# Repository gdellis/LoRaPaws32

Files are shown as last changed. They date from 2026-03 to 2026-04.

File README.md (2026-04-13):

# LoRaPaws32

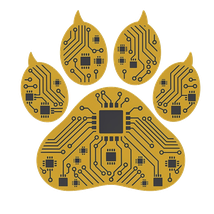
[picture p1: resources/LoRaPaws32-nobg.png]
LoRaPaws32 Logo








LoRa-based pet tracker using LoRa radio to communicate with a home base station, which forwards data to the cloud.

## Features

- **GPS tracking** with NEO-6M module and ~2.5m accuracy
- **LoRa radio** (SX1262) for long-range communication to base station
- **BLE fallback** for direct phone connectivity when in range
- **Motion detection** via LIS3DH accelerometer for intelligent wake cycles
- **Deep sleep** for maximum battery life
- **Web UI** on base station for live tracking and configuration

## Hardware

| Component | Part |
|---|---|
| MCU | ESP32-C6 (RISC-V) |
| LoRa | Seeed Wio-SX1262 for XIAO (915 MHz) |
| GPS | u-blox NEO-6M |
| Accelerometer | LIS3DH |
| Battery | LiPo 500mAh |

See [docs/hardware/DESIGN.md](docs/hardware/DESIGN.md) for full hardware documentation.

## Architecture

```mermaid
flowchart LR
    T[Tracker<br/>ESP32C6] <-->|BLE| P[Phone]
    T -->|LoRa| B[Base Station<br/>Raspberry Pi]
    B -->|MQTT| H[(HiveMQ<br/>Broker)]
    B -->|HTTP| W[Web UI<br/>Flask]
```

## Project Structure

```
LoRaPaws32/
├── firmware/              # C++ ESP-IDF firmware
│   ├── CMakeLists.txt
│   ├── build.sh          # Docker-based build
│   ├── sdkconfig.defaults
│   └── main/
│       └── main.cpp       # Application entry
├── hardware/              # KiCad PCB designs & enclosure
│   ├── tracker/          # Pet tracker PCB
│   ├── base_station/     # Base station PCB
│   └── enclosure/        # 3D printed case
├── base_station/         # Python Flask web app
├── docs/                 # Documentation
│   ├── hardware/         # Hardware design docs
│   ├── firmware/         # Firmware docs
│   ├── datasheets/       # Component datasheets
│   └── plans/            # Implementation plans
├── third_party/          # Vendor libraries
└── .github/workflows/     # CI/CD pipelines
```

## Firmware

Built with C++ and ESP-IDF framework using Docker.

### Prerequisites

- Docker

### Build

```bash
cd firmware
./build.sh
```

### IDE Setup

**Note:** The ESP-IDF framework uses the Xtensa toolchain (Xtensa-specific compiler
flags like `-mlongcalls`, `-fno-shrink-wrap`, `-fstrict-volatile-bitfields`).
When using clangd or other GCC-based LSP servers, you may see warnings such as:

```
Unknown argument '-mlongcalls'; did you mean '-mlong-calls'?
Unknown argument: '-fno-shrink-wrap'
Unknown argument: '-fstrict-volatile-bitfields'
```

These warnings are expected and do not affect the build. They occur because:
- ESP-IDF compiles with `xtensa-esp-elf-gcc` which accepts Xtensa-specific flags
- Host-based tests use standard GCC
- clangd uses host GCC which doesn't recognize these flags

The warnings are cosmetic and can be safely ignored. Actual compilation uses the correct
toolchain via `idf.py build` or `./build.sh`.

### Flash

```bash
docker run --rm -v $(pwd):/workspace -w /workspace espressif/idf:v5.3.1 \
  sh -c ". /opt/esp/idf/export.sh && idf.py -p /dev/ttyACM0 flash monitor"
```

## Base Station

Python 3 on Raspberry Pi with:
- Flask web server
- SQLite database
- Leaflet.js + OpenStreetMap for live tracking

## Documentation

| Document | Description |
|---|---|
| [docs/hardware/DESIGN.md](docs/hardware/DESIGN.md) | Full hardware design |
| [docs/hardware/BOM.md](docs/hardware/BOM.md) | Bill of materials |
| [docs/plans/](docs/plans/) | Implementation plans |
| [docs/firmware/DEPENDENCIES.md](docs/firmware/DEPENDENCIES.md) | Build dependencies |

## License

- **Firmware** (`firmware/`): [Personal Use Only](LICENSE)
- **Hardware & Documentation** (`hardware/`, `docs/`): [CC BY-NC-SA 4.0](LICENSE-DESIGNS)

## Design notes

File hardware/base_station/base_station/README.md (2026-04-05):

# Base Station KiCad Project

KiCad 8 project for the pet tracker base station carrier board.

## Project Files

```
base_station/
├── base_station.kicad_pro   # Project file (open this in KiCad)
├── base_station.kicad_sch   # Schematic
├── base_station.kicad_pcb   # PCB layout
└── sym/                     # Custom symbol library
    └── base_station.kicad_sym
```

## Components

| Ref | Component | Footprint |
|-----|---|---|
| U1 | XIAO ESP32S3 | SeeedStudio:XIAO-ESP32S3 |
| U2 | NEO-6M GPS | GPS:GPS-NEO-6M |
| U3 | MCP1700 LDO | Package_TO_SOT_SMD:SOT-23-3 |
| J1 | USB-C | Connector_USB:USB_C_Receptacle |
| J2 | Battery | Connector_JST:JST_PH_B2B-PH-K |
| D1 | Status LED | Device:LED_0603 |
| R1 | LED Resistor (470R) | Resistor_SMD:R_0603_1608Metric |
| C1 | Decoupling Cap (10µF) | Capacitor_SMD:C_0603_1608Metric |

## Pin Connections

| Signal | XIAO Pin | Connection |
|---|---|---|
| GPS_TX | D7 (GPIO6) | GPS RX |
| GPS_RX | D6 (GPIO7) | GPS TX |
| GPS_PPS | D0 (GPIO0) | GPS PPS (optional) |
| LED_STATUS | D10 (GPIO10) | R1 → LED |

## Setup

1. Initialize the OPL submodule:

   ```bash
   git submodule update --init --recursive
   ```

2. Open `base_station.kicad_pro` in KiCad 8+

3. Configure library paths:
   - **Symbol Libraries**: Add
     `../../third_party/OPL_Kicad_Library/Seeed Studio XIAO ESP32S3/lib/` and
     `../../third_party/OPL_Kicad_Library/Seeed Studio Wio SX1262 for XIAO ESP32S3/lib/`
   - **Footprint Libraries**: Same paths with `.pretty` suffix

4. Add components from libraries to schematic

5. Run ERC (Electrical Rules Check) and DRC (Design Rules Check)

## Notes

- This is a starting point — verify all connections against component datasheets
- The Wio-SX1262 stacks on XIAO via board-to-board connector (no wiring needed)
- GPS module is powered from XIAO's 3.3V rail
- Battery (3.7V LiPo) → MCP1700 → 3.3V for XIAO
- Board outline: 100mm x 80mm (adjust as needed)

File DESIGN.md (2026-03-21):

# Pet Tracker ESP32 Design

## Overview

An ESP32-based pet tracker using LoRa radio to communicate with a home base station,
which forwards data to the cloud. The device sleeps deeply between updates to maximize
battery life, waking only to acquire GPS and transmit.

**Target use case**: Pets that roam outdoors, tracked via a home base station with
cloud connectivity for remote monitoring via mobile app.

---

## Hardware

### Main Board: Seeed Studio XIAO ESP32C3

- **MCU**: ESP32-C3 (RISC-V, 160 MHz, WiFi/Bluetooth 5.0 LE)
- **Flash**: 4 MB
- **USB**: USB-C for charging and programming
- **Size**: 21 x 17.5 mm — very compact
- **Note**: ESP32-C3 has no floating-point unit (no FPU). Keep math simple or use soft-float.

### Alternative Board: XIAO ESP32S3

- **MCU**: ESP32-S3 (Xtensa, 240 MHz, with FPU)
- **Bluetooth 5.0 LE + BLE
- **USB**: USB-C
- **Size**: 21 x 17.5 mm
- **Preferred if**: You want BLE fallback for direct phone connectivity and better floating-point performance

**Recommendation**: Use **ESP32-S3** for headroom (FPU, more RAM, BLE support).

### GPS Module: u-blox NEO-6M (or compatible)

- **Interface**: UART (TX/RX)
- **Accuracy**: ~2.5 m CEP
- **Operating voltage**: 2.7–3.6 V
- **Cold start**: ~27 s typical
- **Hot start**: ~1 s
- **Active current**: ~20–25 mA during acquisition
- **Sleep current**: ~1 mA (if supported)

**Pin Mapping (XIAO → GPS)**:

| XIAO Pin | GPS Module | Function |
|---|---|---|
| D4 (GPIO20) | TX | GPS data out → XIAO RX |
| D5 (GPIO21) | RX | XIAO data out → GPS TX |
| 3V3 | VCC | Power (or via LDO if needed) |
| GND | GND | Ground |

**Alternative GPS modules**:

- **MAX-M10S**: Lower power (~15 mA), faster fix, U-blox M10 platform
- **Quectel L76B**: Integrated, cheaper, but higher power
- **ATGM336H**: Very cheap, adequate for pet tracker use case

**Note**: NEO-6M is 3.3V compatible but draws significant current. Consider using a GPIO-controlled power switch to completely cut power between GPS fixes.

### Power Management

- **LDO**: Low-dropout regulator (e.g., MCP1700, 3.3 V output) for stable power
- **Voltage divider**: For battery voltage monitoring via ADC (measure Vbat)
- **Power switch**: GPIO-controlled MOSFET to cut GPS power when not in use
- **Sleep current target**:
  - SX1262: ~1 µA (very low, LoRa radio itself)
  - ESP32-S3 deep sleep: ~10–20 µA (CPU off, RTC memory retained)
  - GPS: Must be powered off completely (no true sleep on NEO-6M)
  - **Total target in deep sleep**: < 50 µA

**Power architecture**:

```
LiPo (3.7V) → MCP1700 (3.3V) → XIAO + Wio-SX1262
                    ↓
            GPIO-controlled switch → GPS module
                    ↓
            ADC voltage divider → Battery monitoring
```

### Other Components

- **Indicator LED**: Single RGB or single-color LED for status (low current, ~5 mA)
- **Reset button**: Tactile button for manual reset
- **Antenna connectors**: U.FL for LoRa (Wio-SX1262 has built-in U.FL)
- **Accelerometer**: LIS3DH (I2C) for motion detection — wakes device when pet moves
- **3D printed enclosure**: Custom case for XIAO + Wio-SX1262 + GPS + LIS3DH + battery
  - Consider: PETG or ABS for durability
  - Needs antenna clearance (LoRa U.FL antenna on top of stack)
  - Waterproofing: **silicone gasket** (reusable, adjustable, good seal)

---

## Software Architecture

### Firmware Overview

The tracker firmware is event-driven, built on ESP-IDF's FreeRTOS. Most time is spent in deep sleep; on wake, the system acquires GPS, transmits via LoRa, then returns to sleep.

```mermaid
stateDiagram-v2
    [*] --> BOOT
    BOOT --> IDLE

    state IDLE {
        [*] --> WAITING
        WAITING --> WAITING : no wake source
    }

    IDLE --> ACQUIRING_GPS : wake (timer/button/motion)
    IDLE --> STANDBY : immediate sleep

    state ACQUIRING_GPS {
        [*] --> GPS_POWER_ON
        GPS_POWER_ON --> GPS_WAIT_FIX
        GPS_WAIT_FIX --> GPS_WAIT_FIX : no fix yet
        GPS_WAIT_FIX --> GPS_FIX_OK : valid fix
        GPS_WAIT_FIX --> GPS_TIMEOUT : 60s elapsed
        GPS_TIMEOUT --> GPS_POWER_OFF
        GPS_FIX_OK --> GPS_POWER_OFF
        GPS_POWER_OFF --> [*]
    }

    ACQUIRING_GPS --> TRANSMITTING : fix acquired or timeout
    TRANSMITTING --> STANDBY : TX complete

    state STANDBY {
        [*] --> DEEP_SLEEP
        DEEP_SLEEP --> [*] : wake source fires
    }

    STANDBY --> IDLE : wake source
```

### Module Structure

```
src/
├── main.rs           # Boot, initialization, main task
├── lib.rs            # Library root, shared types, error types
├── gps.rs            # GPS parsing (NMEA), location data types
├── lora/
│   ├── mod.rs        # LoRa trait/interface + shared types
│   └── sx1262.rs     # SX1262 driver implementation
├── power.rs          # Sleep, wake sources, battery monitoring
├── accelerometer.rs  # LIS3DH I2C driver for motion detection
├── ble.rs            # BLE GATT server for direct phone connectivity
├── geofence.rs       # Geofence checking (circle/polygon)
├── config.rs         # NVS storage for device config
└── error.rs          # Error types
```

### Key Interfaces

**GPS Module** (`gps.rs`):

```rust
pub struct GpsData {
    pub latitude:  i32,  // degrees * 1e6
    pub longitude: i32,  // degrees * 1e6
    pub altitude:  u16,  // meters
    pub valid:    bool,
    pub timestamp: u32, // Unix epoch
}

pub trait GpsDriver {
    fn power_on(&mut self) -> Result<()>;
    fn power_off(&mut self) -> Result<()>;
    fn read_fix(&mut self, timeout_ms: u32) -> Result<GpsData>;
}
```

**LoRa Driver** (`lora/mod.rs`):

```rust
pub struct RadioPacket {
    pub device_id:  u32,
    pub latitude:   i32,
    pub longitude:  i32,
    pub altitude:   u16,
    pub battery_mv: u16,
    pub flags:      u8,
    pub timestamp:  u32,
}

pub trait LoRaDriver {
    fn init(&mut self) -> Result<()>;
    fn send(&mut self, packet: &RadioPacket) -> Result<()>;
    fn sleep(&mut self) -> Result<()>;
}
```

**Power Management** (`power.rs`):

```rust
pub enum WakeSource {
    Timer(u32),        // RTC timer, duration in ms
    GpsTimeout,
    Button,
}

pub fn enter_deep_sleep(wake_source: WakeSource) -> !;
pub fn get_battery_voltage() -> u16;  // mV
```

### State Machine Detail

**State: STANDBY (Deep Sleep)**

- CPU off, RTC running
- Wake on: RTC timer, button press
- On wake: transition to IDLE then to appropriate state

**State: ACQUIRING_GPS**

- Turn on GPS via power switch (GPIO MOSFET)
- Poll UART for NMEA sentences (GGA, RMC)
- Parse for valid fix (latitude/longitude present)
- Timeout after 60 s → transmit with `valid=false`
- On valid fix: transition to TRANSMITTING

**State: TRANSMITTING**

- Build 20-byte packet
- Wake SX1262 from sleep
- Configure (SF7, BW125, CR4/5, +17 dBm)
- Send packet
- Wait for ACK or timeout (max 3 retries)
- Transition to STANDBY (deep sleep)

### Timing Configuration

```rust
// Configurable constants
const GPS_TIMEOUT_MS: u32 = 60_000;        // 60 seconds max GPS acquisition
const TX_RETRIES: u8 = 3;
const TX_TIMEOUT_MS: u32 = 5_000;         // Per retry timeout

// Default wake intervals (stored in NVS, configurable)
const DEFAULT_SLEEP_INTERVAL_MS: u32 = 60_000;  // 1 minute when moving
const STATIONARY_SLEEP_INTERVAL_MS: u32 = 300_000;  // 5 minutes when stationary
```

### Startup Sequence

1. **Boot** (ROM bootloader → ESP-IDF bootloader)
2. **Early init**: Configure cache, CPU frequency, Flash
3. **ESP-IDF components init**: System, WiFi (disabled), Bluetooth (disabled)
4. **Rust runtime init**: Global allocator, panic handler
5. **Driver init**:
   - Configure GPIO (power switch, LED, button)
   - Initialize SX1262 (but keep in sleep)
   - Initialize GPS (keep powered off)
6. **Read config** from NVS (device_id, sleep intervals, geofences)
7. **Check wake source**: Timer vs button vs reset
8. **Enter main loop** or **deep sleep**

### Error Handling

```rust
#[derive(Debug, Clone, Copy)]
pub enum TrackerError {
    GpsNoFix,
    GpsTimeout,
    LoraTxFailed,
    LoraNoAck,
    NvsError,
    InvalidConfig,
}

impl TrackerError {
    pub fn is_recoverable(&self) -> bool {
        matches!(self, GpsNoFix | GpsTimeout | LoraTxFailed | LoraNoAck)
    }
}
```

- **Recoverable errors**: Log, continue (e.g., no GPS fix → transmit with valid=false)
- **Unrecoverable errors**: Panic and reboot (e.g., NVS corruption)
- All errors logged via `log::error!` for diagnostics

### Configuration Storage (NVS)

Stored in flash via ESP-IDF's NVS:

| Key | Type | Default | Description |
|-----|---|---|---|
| device_id | u32 | random | Unique device identifier |
| sleep_interval_ms | u32 | 60000 | Normal wake interval |
| stationary_interval_ms | u32 | 300000 | Interval when stationary |
| tx_power | u8 | 17 | LoRa TX power in dBm |
| sf | u8 | 7 | Spreading factor |
| geofence_count | u8 | 0 | Number of configured zones |
| motion_threshold | u16 | 100 | LIS3DH motion threshold (mg) |
| stationary_timeout_ms | u32 | 300000 | Time without motion to be "stationary" |

### Interrupt Handlers

Minimal interrupt handlers in embedded context:

- **GPIO button**: Wake from deep sleep on button press
- **Timer**: Wake from deep sleep on RTC alarm
- **LIS3DH INT1**: Motion detected interrupt (wake on movement)
- **SX1262 DIO1**: Packet TX/RX done interrupt (optional, polling also works)

All heavy processing deferred to main task.

### Base Station (Python on Raspberry Pi)

Raspberry Pi with LoRa hat (e.g., Raspberry Pi LoRa HAT):

```mermaid
flowchart LR
    A[LoRa RX] --> B[Python Parser]
    B --> C[WiFi MQTT Publish]
    C --> D[HiveMQ Broker]
    C --> E[(Optional ACK<br/>to tracker)]
```

- LoRa receiver always listening
- Python script parses packet, publishes to HiveMQ via WiFi
- Optional ACK sent back to tracker after successful publish
- **Web UI** for configuration and live data viewing (Flask + HTML/JS)

### Base Station Web UI

A lightweight Flask web server runs on the Raspberry Pi, providing:

**Features**:
- **Dashboard**: Live view of all tracked pets (location, battery, signal strength)
- **Map view**: OpenStreetMap integration showing pet locations in real-time
- **Configuration**: WiFi SSID/password, MQTT broker address, LoRa settings
- **Geofence management**: Add/edit/delete geofence zones
- **Device management**: Register new trackers, view device status
- **Alerts**: Geofence breach notifications (browser notifications)

**Tech stack**:
- **Backend**: Python Flask (lightweight, runs on Pi Zero 2 W)
- **Frontend**: HTML + CSS + JavaScript (no framework, minimal footprint)
- **Map**: Leaflet.js + OpenStreetMap (free, no API key)
- **Data**: Local SQLite database for history, MQTT for live updates

**Endpoints**:

| Endpoint | Method | Description |
|---|---|---|
| `/` | GET | Dashboard with map and pet list |
| `/api/devices` | GET | List all registered devices |
| `/api/devices/<id>` | GET | Device details and latest location |
| `/api/devices/<id>/history` | GET | Location history (query params: from, to) |
| `/api/config` | GET/POST | Get/set base station configuration |
| `/api/geofences` | GET/POST/DELETE | Manage geofence zones |
| `/api/stats` | GET | System statistics (MQTT messages/sec, uptime) |

**Web UI Architecture**:

```mermaid
flowchart TB
    subgraph Pi["Raspberry Pi"]
        A[Flask Server] --> B[SQLite DB]
        A --> C[MQTT Client]
        C --> D[LoRa Receiver]
    end
    E[Browser] <--> A
    A --> F[OpenStreetMap<br/>via Leaflet.js]
    D --> C
```

**Configuration stored in SQLite**:

| Table | Fields | Description |
|---|---|---|
| devices | id, name, device_id, created_at | Registered trackers |
| geofences | id, name, device_id, zone_type, coordinates, radius | Fence zones |
| config | key, value | WiFi, MQTT, system settings |
| location_history | device_id, lat, lon, alt, battery, timestamp | Historical data |

### Memory Considerations

- **Stack**: Keep stack usage minimal in ISRs. Main task stack ~4KB
- **Heap**: Dynamic allocation only for packet buffers, GPS NMEA parsing
- **Static**: All drivers and state machine data as static globals
- **No malloc in ISR context**: Use static buffers or stack-only allocations

### LoRa Protocol

Point-to-point LoRa from tracker to base station.

**Packet structure** (compact binary, ~20 bytes):

| Field | Size | Description |
|---|---|---|
| device_id | 4 B | Unique device identifier |
| latitude | 4 B | Fixed-point (e.g., deg * 1e6) |
| longitude | 4 B | Fixed-point (e.g., deg * 1e6) |
| altitude | 2 B | Meters (uint16) |
| battery_mv | 2 B | Battery voltage in millivolts |
| status_flags | 1 B | GPS fix valid, moving, etc. |
| timestamp | 3 B | Unix epoch (seconds, mod 24h) |

**Note**: ESP32-C3 has no built-in RTC. Use Unix timestamp from GPS or NTP sync when WiFi is available.

### Base Station (separate firmware or software)

- Raspberry Pi with Wio-SX1262 or LoRa-E5
- Another XIAO ESP32S3 with stacked Wio-SX1262 makes an excellent base station
- Receives packets from tracker via LoRa
- Forwards via WiFi to cloud (MQTT or HTTP)
- Could also act as a LoRaWAN gateway for multiple trackers

**Base station firmware options**:

1. **XIAO ESP32S3 + Wio-SX1262**: Compact, runs ESP-IDF, same LoRa driver as tracker
2. **Raspberry Pi + LoRa hat**: More compute headroom for complex gateway logic
3. **ESP32 + LoRa-E5**: Simpler firmware but higher sleep current on E5

### Cloud Backend (out of scope for this design, but for completeness)

- MQTT broker → InfluxDB or TimescaleDB → Grafana dashboard
- Optional: Twilio or push notification for geofence breach alerts

---

## LoRa Configuration (SX1262)

**Recommended settings for point-to-point pet tracker**:

| Parameter | Value | Rationale |
|---|---|---|
| Spreading Factor (SF) | SF7–SF9 | Balance of range and speed; SF7 = ~3 km urban |
| Bandwidth (BW) | 125 kHz | Good balance of sensitivity vs speed |
| Coding Rate (CR) | 4/5 | Standard reliability |
| TX Power | +17 dBm | Good range with acceptable current (~120 mA) |
| Preamble length | 12 | Default, robust |

**Lower SF = faster TX = lower battery**. Use the highest SF that gives reliable comms at your typical distances.

**Packet format** (same as tracker-to-base):

```
[device_id: 4][lat: 4][lon: 4][alt: 2][battery_mv: 2][flags: 1][timestamp: 3] = 20 bytes
```

With SF7 + BW125k, ~20 bytes transmits in ~50–100 ms. At +17 dBm, TX current ~120 mA.

---

## Geofencing

### Types

1. **Circular geofence**: Center point + radius. Simple, low compute.
2. **Polygon geofence**: Array of lat/lon vertices. More flexible but more compute.

### Implementation

- Store geofence as a list of zones in config (NVS flash)
- Check point-in-circle: `sqrt((lat-lat0)^2 + (lon-lon0)^2) < radius`
- Use haversine formula for accurate distance on sphere
- **On breach**: Set flag in next transmission, trigger alert from cloud

**Compute constraint**: ESP32-C3 has no FPU. Use integer math or lookup tables for haversine. Consider offloading geofence check to base station or cloud if compute is tight.

---

## Mobile App (Future)

- View current location on map
- Set/edit geofence zones
- Receive push notifications on geofence breach
- View battery level and signal strength
- Historical location trail

**Options**:

- Native Android/iOS with Bluetooth LE connectivity (when in range)
- Progressive Web App (PWA) via base station cloud connection
- MQTT client on phone subscribes to device topics

---

## Power Budget (Estimate)

Using SX1262 sleep current (~1 µA) + LIS3DH (~3 µA in low-power mode):

| State | Current  | Duration  | Charge used (500 mAh) |
|---|---|---|---|
| Deep sleep | 4 µA | ~55 min | 0.004 mAh |
| GPS acquire | 25 mA | 30 s | 0.208 mAh |
| LoRa TX | 120 mA  | 2 s | 0.067 mAh |
| **Per cycle** | | ~60 s | **0.279 mAh** |

At one cycle per minute: 0.279 mAh × 60 min × 24 hours = **~401 mAh/day**

With a 500 mAh battery: **~1.25 days** at 1-minute intervals.

**Motion-triggered wake significantly improves battery life**: If pet is stationary 75% of the time and LIS3DH wakes device only on motion, average daily consumption drops to ~100 mAh/day,
giving **~5 days** battery life.

**To extend battery life**:

- Increase sleep interval when stationary (e.g., 5 min via LIS3DH motion detection)
- Use GPS caching (if velocity is low, reuse last known location)
- Reduce LoRa TX power to minimum needed for reliable comms
- Use lower SF (Spreading Factor) to reduce TX time

---

## Open Questions / Tradeoffs

All questions have been answered:

1. **GPS module choice** → **NEO-6M**: Cheap, reliable, 25 mA during acquisition
2. **LoRa frequency** → **915 MHz (US)**: For North/South America regions
3. **Base station form factor** → **Raspberry Pi + LoRa hat**: (see Base Station section)
4. **Cloud backend** → **HiveMQ** (self-hosted): (see TODO section)
5. **Accelerometer** → **LIS3DH included**: Motion detection for intelligent wake
6. **GPS power switching** → **GPIO-controlled MOSFET**: Essential for low deep-sleep current
7. **Enclosure waterproofing** → **Silicone gasket**: Reusable, adjustable, good seal

---

## Bill of Materials (BOM)

| Component | Part | Est. Cost (USD) | Notes |
|---|---|---|---|
| Main MCU | Seeed Studio XIAO ESP32S3 | $10 | |
| LoRa module | Seeed Wio-SX1262 for XIAO | $15 | |
| GPS | u-blox NEO-6M | $8–15 | or MAX-M10S ($15–20) |
| Accelerometer | LIS3DH | $1–2 | I2C, motion detection |
| Battery | LiPo 503035 500mAh | $5 | Compact LiPo |
| Charger | TP4056 USB-C | $1 | |
| LDO | MCP1700-3302 | $0.30 | |
| MOSFET | BSS138 or AO3400 | $0.10 | For GPS power switch |
| Resistors | For voltage divider | $0.05 | |
| Status LED | RGB SMD 5050 | $0.20 | |
| Enclosure | 3D printed PETG | ~$2 | filament cost |
| **Total (tracker)** | | **~$45–55** | Not including shipping |

**Base station BOM**:

| Component | Part | Est. Cost (USD) | Notes |
|---|---|---|---|
| Single-board computer | Raspberry Pi Zero 2 W | $15 | or Pi 3/4 |
| LoRa hat | SX1262 LoRa HAT for Pi | $15–20 | |
| Power supply | USB-C 5V 2A | $5 | |
| SD card | 16GB | $5 | |
| **Total (base station)** | | **~$40–45** | |

---

## TODO Before Build

- [x] ~~Select final board~~ → **XIAO ESP32S3** (FPU, BLE, more RAM)
- [x] ~~Select LoRa radio~~ → **Wio-SX1262** (SX1262, low power SPI)
- [x] ~~Select base station~~ → **Python on Raspberry Pi** with LoRa hat
- [x] ~~Select MQTT broker~~ → **HiveMQ** (self-hosted)
- [x] ~~Select GPS module~~ → **NEO-6M** (cheap, reliable, 25 mA)
- [x] ~~Select LoRa frequency~~ → **915 MHz (US)**
- [x] ~~Select waterproofing~~ → **Silicone gasket** (reusable, good seal)
- [ ] Design power supply (charger + LDO + power switch for GPS)
- [ ] Verify Wio-SX1262 pin mapping with actual board
- [ ] Order components:
  - [ ] XIAO ESP32S3
  - [ ] Wio-SX1262 (915 MHz variant)
  - [ ] NEO-6M GPS module
  - [ ] LIS3DH accelerometer
  - [ ] LiPo battery (500–1000 mAh)
  - [ ] MCP1700 LDO
  - [ ] TP4056 charger
  - [ ] N-channel MOSFET (for GPS power switching)
  - [ ] Voltage divider resistors (for battery monitoring)
  - [ ] Enclosure materials / 3D printer filament
  - [ ] Raspberry Pi Zero 2 W (for base station)
  - [ ] LoRa hat for Raspberry Pi (for base station)
- [ ] Design PCB or protoboard layout
- [ ] Design 3D-printed enclosure with silicone gasket groove
- [ ] Implement tracker firmware (see Software Architecture)
- [ ] Implement base station Python script
- [ ] Set up HiveMQ broker
- [ ] Set up cloud backend (MQTT broker + database)

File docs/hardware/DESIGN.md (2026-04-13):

# Pet Tracker ESP32-C6 Design

## Overview

An ESP32-C6-based pet tracker using LoRa radio to communicate with a home base station,
which forwards data to the cloud. The device sleeps deeply between updates to maximize
battery life, waking only to acquire GPS and transmit.

**Target use case**: Pets that roam outdoors, tracked via a home base station with
cloud connectivity for remote monitoring via mobile app.

---

## Hardware

### Main Board: ESP32-S3 (primary) / ESP32-C6 (alternate)

**Target**: ESP32-S3-WROOM-1 (primary) or ESP32-C6-WROOM-1C (alternate)

- **ESP32-S3**: Xtensa dual-core 32-bit, 240 MHz, BLE 5.0
- **ESP32-C6**: RISC-V single-core, 160 MHz, BLE 5.0
- **LoRa**: SX1262 (868/915 MHz) via SPI
- **Interfaces**: SPI, UART, I2C, GPIO for GPS/sensor expansion
- **Deep sleep current**: ~10-20 µA (CPU off, RTC memory retained)

### GPS Module: HGLRC M100-5883 (M10, 72ch, multi-GNSS)

- **Interface**: UART (TX/RX at 115200 baud)
- **Accuracy**: ~2.5 m CEP
- **Operating voltage**: 2.7–3.6 V
- **Cold start**: ~27 s typical
- **Hot start**: ~1 s
- **Active current**: ~20–25 mA during acquisition
- **Sleep current**: Must be powered off completely (no true sleep)

**Pin Mapping**:

| ESP32-S3 Pin | ESP32-C6 Pin | GPS Module | Function |
|---|---|---|---|
| GPIO7 | GPIO4 | RX | ESP data out → GPS TX |
| GPIO15 | GPIO5 | TX | GPS data out → ESP RX |
| 3V3 | 3V3 | VCC | Power (via LDO) |
| GND | GND | GND | Ground |

**Note**: GPS draws significant current. Use a GPIO-controlled power switch to completely cut power between GPS fixes.

### LoRa Radio: SX1262

**ESP32-S3 Pin Mapping**:

| ESP32-S3 Pin | SX1262 | Function |
|---|---|---|
| GPIO4 | SPI MOSI | Data out |
| GPIO5 | SPI MISO | Data in |
| GPIO6 | SPI CLK | Clock |
| GPIO8 | NSS | Chip select |
| GPIO1 | Reset | Reset line |
| GPIO2 | BUSY | Busy indicator |
| GPIO3 | DIO1 | Interrupt/done |

**ESP32-C6 Pin Mapping**:

| ESP32-C6 Pin | SX1262 | Function |
|---|---|---|
| GPIO6 | SPI MOSI | Data out |
| GPIO7 | SPI MISO | Data in |
| GPIO8 | SPI CLK | Clock |
| GPIO10 | NSS | Chip select |
| GPIO11 | Reset | Reset line |
| GPIO3 | BUSY | Busy indicator |
| GPIO1 | DIO1 | Interrupt/done |

### Power Management

- **LDO**: Low-dropout regulator (e.g., MCP1700, 3.3 V output) for stable power
- **Voltage divider**: For battery voltage monitoring via ADC (measure Vbat)
- **Power switch**: GPIO-controlled MOSFET to cut GPS power when not in use
- **Sleep current target**:
  - SX1262: ~1 µA (very low, LoRa radio itself)
  - ESP32-C6 deep sleep: ~10–20 µA (CPU off, RTC memory retained)
  - GPS: Must be powered off completely (no true sleep on NEO-6M)
  - **Total target in deep sleep**: < 50 µA

**Power architecture**:

```
LiPo (3.7V) → MCP1700 (3.3V) → ESP32-C6 + SX1262
                    ↓
            GPIO-controlled switch → GPS module
                    ↓
            ADC voltage divider → Battery monitoring
```

### Other Components

- **Indicator LED**: Single LED on GPIO8 (active high)
- **Reset button**: Tactile button on GPIO9 (active low, pulled up)
- **Antenna connectors**: U.FL for LoRa
- **Accelerometer**: LIS3DH (I2C) for motion detection — wakes device when pet moves
- **3D printed enclosure**: Custom case for ESP32-C6 + SX1262 + GPS + LIS3DH + battery
  - Consider: PETG or ABS for durability
  - Needs antenna clearance (LoRa U.FL antenna on top of stack)
  - Waterproofing: **silicone gasket** (reusable, adjustable, good seal)

---

## Software Architecture

### Firmware Overview

The tracker firmware is event-driven, built on ESP-IDF's FreeRTOS. Most time is
spent in deep sleep; on wake, the system acquires GPS, transmits via LoRa, then
returns to sleep.

```mermaid
%%{init: {'theme':'dark'}}%%
stateDiagram-v2
    [*] --> BOOT
    BOOT --> IDLE

    state IDLE {
        [*] --> WAITING
        WAITING --> WAITING : no wake source
    }

    IDLE --> ACQUIRING_GPS : wake (timer/button/motion)
    IDLE --> STANDBY : immediate sleep

    state ACQUIRING_GPS {
        [*] --> GPS_POWER_ON
        GPS_POWER_ON --> GPS_WAIT_FIX
        GPS_WAIT_FIX --> GPS_WAIT_FIX : no fix yet
        GPS_WAIT_FIX --> GPS_FIX_OK : valid fix
        GPS_WAIT_FIX --> GPS_TIMEOUT : 60s elapsed
        GPS_TIMEOUT --> GPS_POWER_OFF
        GPS_FIX_OK --> GPS_POWER_OFF
        GPS_POWER_OFF --> [*]
    }

    ACQUIRING_GPS --> TRANSMITTING : fix acquired or timeout
    TRANSMITTING --> STANDBY : TX complete

    state STANDBY {
        [*] --> DEEP_SLEEP
        DEEP_SLEEP --> [*] : wake source fires
    }

    STANDBY --> IDLE : wake source
```

### Module Structure

```
firmware/
├── CMakeLists.txt           # ESP-IDF root CMake
├── sdkconfig.defaults      # ESP-IDF configuration
├── build.sh                 # Docker-based build script
├── main/
│   ├── main.cpp             # Boot, initialization, main task
│   ├── board_config.h      # Pin mappings for ESP32-S3/C6
│   ├── gpio_driver.cpp     # GPIO abstraction
│   ├── led_driver.cpp      # LED driver
│   ├── button_handler.cpp  # Button debounce
│   ├── gps.cpp             # GPS UART driver
│   ├── nmea_parser.hpp     # Header-only NMEA parsing (testable on host)
│   ├── ble.cpp/.hpp        # BLE GATT server with alert notifications
│   ├── config.cpp/.hpp     # NVS configuration storage
│   ├── geofence.cpp/.hpp   # Circular geofence zone checking
│   ├── accelerometer.cpp/.hpp  # LIS3DH I2C accelerometer driver
│   ├── state_machine.cpp/.hpp  # Main tracker state machine
│   ├── lora/
│   │   ├── sx1262.cpp      # SX1262 LoRa driver
│   │   └── sx1262.hpp
│   └── deep_sleep.hpp      # Deep sleep utility
└── tests/                  # Host-based unit tests with mocks
    ├── test_*.cpp          # Catch2 test suites
    ├── include/            # Mock headers for ESP-IDF
    └── src/                # Mock implementations
```

### Key Interfaces

**GPS Module** (`gps.cpp`, `nmea_parser.hpp`):

```cpp
struct GpsData {
    int32_t latitude;    // degrees * 1e6
    int32_t longitude;   // degrees * 1e6
    int32_t altitude;    // meters * 100 (cm)
    bool valid;          // Fix valid
    uint32_t timestamp;  // Unix epoch
};

class GpsDriver {
public:
    GpsDriver(gpio_num_t tx_pin, gpio_num_t rx_pin);
    void power_on();
    void power_off();
    GpsData read_fix(uint32_t timeout_ms);
};
```

**LoRa Driver** (future):

```cpp
struct RadioPacket {
    uint32_t device_id;
    int32_t latitude;    // degrees * 1e6
    int32_t longitude;   // degrees * 1e6
    int32_t altitude;    // meters * 100 (cm)
    uint16_t battery_mv;
    uint8_t flags;
    uint32_t timestamp;
};

class LoRaDriver {
public:
    LoRaDriver();
    esp_err_t init();
    esp_err_t send(const RadioPacket& packet);
    esp_err_t sleep();
};
```

**Power Management** (`deep_sleep.hpp`):

```cpp
enum class WakeSource {
    Timer(uint32_t duration_ms),
    GpsTimeout,
    Button,
};

void enter_deep_sleep(WakeSource source);
uint16_t get_battery_voltage();  // mV
```

### State Machine Detail

**State: STANDBY (Deep Sleep)**

- CPU off, RTC running
- Wake on: RTC timer, button press
- On wake: transition to IDLE then to appropriate state

**State: ACQUIRING_GPS**

- Turn on GPS via power switch (GPIO MOSFET)
- Poll UART for NMEA sentences (GGA, RMC)
- Parse for valid fix (latitude/longitude present)
- Timeout after 60 s → transmit with `valid=false`
- On valid fix: transition to TRANSMITTING

**State: TRANSMITTING**

- Build 20-byte packet
- Wake SX1262 from sleep
- Configure (SF7, BW125, CR4/5, +17 dBm)
- Send packet
- Wait for ACK or timeout (max 3 retries)
- Transition to STANDBY (deep sleep)

### Timing Configuration

```cpp
// Configurable constants
static constexpr uint32_t GPS_TIMEOUT_MS = 60_000;     // 60 seconds max GPS acquisition
static constexpr uint8_t TX_RETRIES = 3;
static constexpr uint32_t TX_TIMEOUT_MS = 5_000;       // Per retry timeout

// Default wake intervals (stored in NVS, configurable)
static constexpr uint32_t DEFAULT_SLEEP_INTERVAL_MS = 300_000;     // 5 minutes when moving
static constexpr uint32_t STATIONARY_SLEEP_INTERVAL_MS = 600_000; // 10 minutes when stationary
static constexpr int8_t DEFAULT_TX_POWER_DBM = 22;               // +22 dBm
static constexpr uint8_t DEFAULT_SPREADING_FACTOR = 7;            // SF7
```

### Startup Sequence

1. **Boot** (ROM bootloader → ESP-IDF bootloader)
2. **Early init**: Configure cache, CPU frequency, Flash
3. **ESP-IDF components init**: System, WiFi (disabled), Bluetooth (disabled)
4. **Driver init**:
   - Configure GPIO (power switch, LED, button)
   - Initialize SX1262 (but keep in sleep)
   - Initialize GPS (keep powered off)
5. **Read config** from NVS (device_id, sleep intervals, geofences)
6. **Check wake source**: Timer vs button vs reset
7. **Enter main loop** or **deep sleep**

### Error Handling

```cpp
enum class TrackerError {
    GpsNoFix,
    GpsTimeout,
    LoraTxFailed,
    LoraNoAck,
    NvsError,
    InvalidConfig,
};

constexpr bool is_recoverable(TrackerError err) {
    return err == TrackerError::GpsNoFix ||
           err == TrackerError::GpsTimeout ||
           err == TrackerError::LoraTxFailed ||
           err == TrackerError::LoraNoAck;
}
```

- **Recoverable errors**: Log, continue (e.g., no GPS fix → transmit with valid=false)
- **Unrecoverable errors**: Panic and reboot (e.g., NVS corruption)
- All errors logged via `ESP_LOGW`/`ESP_LOGE` for diagnostics

### Configuration Storage (NVS)

Stored in flash via ESP-IDF's NVS:

| Key | Type | Default | Description |
|-----|---|---|---|
| device_id | u32 | random | Unique device identifier |
| sleep_interval_ms | u32 | 60000 | Normal wake interval |
| stationary_interval_ms | u32 | 300000 | Interval when stationary |
| tx_power | u8 | 17 | LoRa TX power in dBm |
| sf | u8 | 7 | Spreading factor |
| geofence_count | u8 | 0 | Number of configured zones |
| motion_threshold | u16 | 100 | LIS3DH motion threshold (mg) |
| stationary_timeout_ms | u32 | 300000 | Time without motion to be "stationary" |

### Interrupt Handlers

Minimal interrupt handlers in embedded context:

- **GPIO button**: Wake from deep sleep on button press
- **Timer**: Wake from deep sleep on RTC alarm
- **LIS3DH INT1**: Motion detected interrupt (wake on movement)
- **SX1262 DIO1**: Packet TX/RX done interrupt (optional, polling also works)

All heavy processing deferred to main task via FreeRTOS queues.

### Base Station (Python on Raspberry Pi)

Raspberry Pi with LoRa hat (e.g., Raspberry Pi LoRa HAT):

```mermaid
%%{init: {'theme':'dark'}}%%
flowchart LR
    A[LoRa RX] --> B[Python Parser]
    B --> C[MQTT Bridge]
    C <--> D[HiveMQ Broker]
    C <--> E[(Phone App<br/>via MQTT)]
    A <--|ACK| B
    B <--|Command| C
```

**Roles**:

1. **LoRa gateway**: Receives packets from trackers, sends ACKs
2. **MQTT bridge**: Forwards tracker data to HiveMQ, receives commands from phone app
3. **Command relay**: Forwards commands from phone → LoRa → tracker

**Flows**:

- **Tracker → Phone**: Tracker LoRa → Base Station → HiveMQ → Phone App
- **Phone → Tracker**: Phone App → HiveMQ → Base Station → LoRa → Tracker

**Web UI** for configuration and live data viewing (Flask + HTML/JS)

### Base Station Web UI

A lightweight Flask web server runs on the Raspberry Pi, providing:

**Features**:
- **Dashboard**: Live view of all tracked pets (location, battery, signal strength)
- **Map view**: OpenStreetMap integration showing pet locations in real-time
- **Configuration**: WiFi SSID/password, MQTT broker address, LoRa settings
- **Geofence management**: Add/edit/delete geofence zones
- **Device management**: Register new trackers, view device status
- **Alerts**: Geofence breach notifications (browser notifications)

**Tech stack**:
- **Backend**: Python Flask (lightweight, runs on Pi Zero 2 W)
- **Frontend**: HTML + CSS + JavaScript (no framework, minimal footprint)
- **Map**: Leaflet.js + OpenStreetMap (free, no API key)
- **Data**: Local SQLite database for history, MQTT for live updates

**Endpoints**:

| Endpoint | Method | Description |
|---|---|---|
| `/` | GET | Dashboard with map and pet list |
| `/api/devices` | GET | List all registered devices |
| `/api/devices/<id>` | GET | Device details and latest location |
| `/api/devices/<id>/history` | GET | Location history (query params: from, to) |
| `/api/config` | GET/POST | Get/set base station configuration |
| `/api/geofences` | GET/POST/DELETE | Manage geofence zones |
| `/api/stats` | GET | System statistics (MQTT messages/sec, uptime) |

**Web UI Architecture**:

```mermaid
%%{init: {'theme':'dark'}}%%
flowchart TB
    subgraph Pi["Raspberry Pi"]
        A[Flask Server] --> B[SQLite DB]
        A --> C[MQTT Client]
        C --> D[LoRa Receiver]
    end
    E[Browser] <--> A
    A --> F[OpenStreetMap<br/>via Leaflet.js]
    D --> C
```

**Configuration stored in SQLite**:

| Table | Fields | Description |
|---|---|---|
| devices | id, name, device_id, created_at | Registered trackers |
| geofences | id, name, device_id, zone_type, coordinates, radius | Fence zones |
| config | key, value | WiFi, MQTT, system settings |
| location_history | device_id, lat, lon, alt, battery, timestamp | Historical data |

### Memory Considerations

- **Stack**: Keep stack usage minimal in ISRs. Main task stack ~4KB
- **Heap**: Avoid dynamic allocation; prefer static buffers and stack-only
- **Static**: All drivers and state machine data as static globals or singleton classes
- **No malloc in ISR context**: Use static buffers or stack-only allocations

### LoRa Protocol

Point-to-point LoRa from tracker to base station.

**Packet structure** (compact binary, ~20 bytes):

| Field | Size | Description |
|---|---|---|
| device_id | 4 B | Unique device identifier |
| latitude | 4 B | Fixed-point (e.g., deg * 1e6) |
| longitude | 4 B | Fixed-point (e.g., deg * 1e6) |
| altitude | 4 B | Centimeters (int32) |
| battery_mv | 2 B | Battery voltage in millivolts |
| status_flags | 1 B | GPS fix valid, moving, etc. |
| timestamp | 4 B | Unix epoch (seconds) |

**Note**: ESP32-C3/C6 has no built-in RTC. Use Unix timestamp from GPS or NTP sync when WiFi is available.

### Base Station (separate firmware or software)

- Raspberry Pi with Wio-SX1262 or LoRa-E5
- Another ESP32-C6 with stacked SX1262 makes an excellent base station
- Receives packets from tracker via LoRa
- Forwards via WiFi to cloud (MQTT or HTTP)

**Base station firmware options**:

1. **ESP32-C6 + SX1262**: Compact, runs ESP-IDF, same LoRa driver as tracker
2. **Raspberry Pi + LoRa hat**: More compute headroom for complex gateway logic
3. **ESP32 + LoRa-E5**: Simpler firmware but higher sleep current on E5

### Cloud Backend (out of scope for this design, but for completeness)

- MQTT broker → InfluxDB or TimescaleDB → Grafana dashboard
- Optional: Twilio or push notification for geofence breach alerts

---

## LoRa Configuration (SX1262)

**Recommended settings for point-to-point pet tracker**:

| Parameter | Value | Rationale |
|---|---|---|
| Spreading Factor (SF) | SF7–SF9 | Balance of range and speed; SF7 = ~3 km urban |
| Bandwidth (BW) | 125 kHz | Good balance of sensitivity vs speed |
| Coding Rate (CR) | 4/5 | Standard reliability |
| TX Power | +17 dBm | Good range with acceptable current (~120 mA) |
| Preamble length | 12 | Default, robust |

**Lower SF = faster TX = lower battery**. Use the highest SF that gives reliable comms at your typical distances.

**Packet format** (same as tracker-to-base):

```
[device_id: 4][lat: 4][lon: 4][alt: 4][battery_mv: 2][flags: 1][timestamp: 4] = 23 bytes
```

With SF7 + BW125k, ~23 bytes transmits in ~50–100 ms. At +17 dBm, TX current ~120 mA.

---

## Geofencing

### Types

1. **Circular geofence**: Center point + radius. Simple, low compute.
2. **Polygon geofence**: Array of lat/lon vertices. More flexible but more compute.

### Implementation

- Store geofence as a list of zones in config (NVS flash)
- Check point-in-circle: `sqrt((lat-lat0)^2 + (lon-lon0)^2) < radius`
- Use haversine formula for accurate distance on sphere
- **On breach**: Set flag in next transmission, trigger alert from cloud

**Compute constraint**: ESP32-C6 is RISC-V but no FPU. Use integer math or
lookup tables for haversine. Consider offloading geofence check to base
station or cloud if compute is tight.

---

## Mobile App (Future)

Mobile app connects to HiveMQ broker via base station's MQTT bridge to receive location updates and send commands.

```mermaid
%%{init: {'theme':'dark'}}%%
flowchart LR
    T[Tracker] -->|LoRa| B[Base Station]
    B -->|MQTT| H[(HiveMQ<br/>Broker)]
    P[Phone App] <-->|REST/MQTT| H
    P <-->|BLE| T
```

**Features**:

- View current location on map (OpenStreetMap or Google Maps)
- Set/edit geofence zones (synced via MQTT)
- Receive push notifications on geofence breach
- View battery level and signal strength
- Historical location trail

**Connectivity options**:

| Method | When | Protocol |
|---|---|---|
| Direct BLE | Phone within ~10m of tracker | BLE GATT |
| Via HiveMQ | Phone anywhere with internet | MQTT over WebSocket |
| Via base station | Phone on local network | HTTP REST |

**Tech stack options**:

- **PWA** (recommended): Works on iOS/Android via browser, no app store required
- **Native**: Swift/SwiftUI (iOS) or Kotlin/Jetpack (Android)
- **Both**: PWA as fallback, native app for push notifications

**MQTT Topics**:

| Topic | Direction | Payload |
|---|---|---|
| `pettracker/{device_id}/location` | Base → Phone | `{lat, lon, battery, timestamp}` |
| `pettracker/{device_id}/status` | Base → Phone | `{rssi, moving, geofence_breach}` |
| `pettracker/{device_id}/command` | Phone → Base → Tracker | `{cmd: "ping" \| "config" \| "alarm"}` |
| `pettracker/{device_id}/config` | Phone → Base → Tracker | `{sleep_interval, geofences}` |

The base station acts as an MQTT bridge: it receives LoRa packets and republishes
to HiveMQ, and forwards commands from the phone app to the tracker via LoRa.

---

## Power Budget (Estimate)

Using SX1262 sleep current (~1 µA) + LIS3DH (~3 µA in low-power mode):

| State | Current  | Duration  | Charge used (500 mAh) |
|---|---|---|---|
| Deep sleep | 4 µA | ~55 min | 0.004 mAh |
| GPS acquire | 25 mA | 30 s | 0.208 mAh |
| LoRa TX | 120 mA  | 2 s | 0.067 mAh |
| **Per cycle** | | ~60 s | **0.279 mAh** |

At one cycle per minute: 0.279 mAh × 60 min × 24 hours = **~401 mAh/day**

With a 500 mAh battery: **~1.25 days** at 1-minute intervals.

**Motion-triggered wake significantly improves battery life**: If pet is stationary
75% of the time and LIS3DH wakes device only on motion, average daily consumption
drops to ~100 mAh/day, giving **~5 days** battery life.

**To extend battery life**:

- Increase sleep interval when stationary (e.g., 5 min via LIS3DH motion detection)
- Use GPS caching (if velocity is low, reuse last known location)
- Reduce LoRa TX power to minimum needed for reliable comms
- Use lower SF (Spreading Factor) to reduce TX time

---

## Open Questions / Tradeoffs

All questions have been answered:

1. **GPS module choice** → **NEO-6M**: Cheap, reliable, 25 mA during acquisition
2. **LoRa frequency** → **915 MHz (US)**: For North/South America regions
3. **Base station form factor** → **Raspberry Pi + LoRa hat**: (see Base Station section)
4. **Cloud backend** → **HiveMQ** (self-hosted): (see TODO section)
5. **Accelerometer** → **LIS3DH included**: Motion detection for intelligent wake
6. **GPS power switching** → **GPIO-controlled MOSFET**: Essential for low deep-sleep current
7. **Enclosure waterproofing** → **Silicone gasket**: Reusable, adjustable, good seal

---

## Bill of Materials (BOM)

See [BOM.md](BOM.md) for full component list with part numbers, pricing, vendor links, and order checklist.

---

## PCB Design Tools

For designing the tracker PCB or base station carrier board.

### Full-Suite EDA Tools

| Tool | Platform | Cost | AI Features | Strengths | Weaknesses |
|---|---|---|---|---|---|
| **KiCad** | Windows/Mac/Linux | Free, open-source | Community plugins | Full schematic capture, large library, no restrictions | Steep learning curve |
| **EasyEDA** | Web + Desktop | Free tier | AI-assisted routing, auto-placement | Cloud-based, large part library, AI features | Data stored on cloud, limited export options |
| **Altium Designer** | Windows | ~$7k/year | AI rule checking, auto-routing | Industry standard, powerful DRC, extensive features | Expensive, Windows only |
| **Cadence OrCAD** | Windows | ~$10k+ | AI optimization | Enterprise-grade, best for complex RF/high-speed | Very expensive, complex workflow |
| **Flux AI** | Web | Free tier available | AI schematic generation, auto-routing | Modern UI, AI-native design | Relatively new, library may be limited |
| **Upverter** | Web | Free tier | AI-assisted design | Collaborative, cloud-based, Git integration | Requires internet, limited offline use |
| **Mentor Graphics (NX)** | Windows | Expensive | AI routing optimization | Best for complex multi-layer boards | Cost prohibitive for hobbyists |

### PCB Routing-Specific AI Tools

| Tool | Cost | Best For | Limitations |
|---|---|---|---|
| **RouterAI** | Free tier | Optimized auto-routing | Limited to routing only |
| **DeepRoute** | Free tier | High-density PCBs | Schematic entry separate |

### Recommendations for This Project

For a simple 2-layer pet tracker PCB:

1. **EasyEDA** (easiest to start, AI-assisted placement/routing)
2. **KiCad** (full control, no cloud dependency)
3. **Flux AI** (modern AI features, good for prototyping)

For the base station carrier board with Raspberry Pi header:
- **KiCad** (best for open-source, full control)
- **EasyEDA** (faster for simple boards)

### When AI PCB Tools Help

- Initial component placement suggestions
- Basic auto-routing for 2-layer boards
- Design rule checking
- Manufacturing file generation (Gerber, drill files)

### When Human Expertise Still Required

- High-speed signal integrity (DDR, USB, RF)
- Multi-layer boards (4+ layers)
- Antenna/RF design
- Differential pair routing
- EMI/EMC optimization

---

## TODO Before Build

- [x] ~~Select final board~~ → **ESP32-S3** (primary) / **ESP32-C6** (alternate)
- [x] ~~Select LoRa radio~~ → **SX1262** (low power SPI)
- [x] ~~Select base station~~ → **Python on Raspberry Pi** with LoRa hat
- [x] ~~Select MQTT broker~~ → **HiveMQ** (self-hosted)
- [x] ~~Select GPS module~~ → **M10/M100-5883** (10Hz, 72ch, multi-GNSS)
- [x] ~~Select LoRa frequency~~ → **915 MHz (US)**
- [x] ~~Select waterproofing~~ → **Silicone gasket** (reusable, good seal)
- [x] ~~Implement deep sleep feature~~ → Merged PR #1
- [x] ~~Implement GPS driver with NMEA parsing~~ → Merged PR #2
- [x] ~~Implement unit tests with mocks~~ → PR #3, PR #7
- [x] ~~Implement LoRa SX1262 driver~~ → PR #6, PR #7
- [x] ~~Implement BLE GATT server~~ → PR #9
- [x] ~~Implement LIS3DH accelerometer~~ → PR #10
- [x] ~~Implement state machine~~ → PR #11
- [x] ~~Implement NVS config storage~~ → PR #12
- [x] ~~Implement geofencing~~ → PR #13, PR #14
- [x] ~~Implement motion-aware sleep~~ → PR #11
- [x] ~~Fix BLE critical bugs~~ → PR #23
- [x] ~~Add GPS + geofence integration tests~~ → PR #24
- [ ] Design power supply (charger + LDO + power switch for GPS)
- [ ] Implement GPS power switching (MOSFET control)
- [ ] Implement battery ADC reading
- [ ] Verify SX1262 pin mapping with actual board
- [ ] Order components:
  - [ ] ESP32-S3 or ESP32-C6 module
  - [ ] SX1262 (915 MHz variant)
  - [ ] M10/M100-5883 GPS module
  - [ ] LIS3DH accelerometer
  - [ ] LiPo battery (500–1000 mAh)
  - [ ] MCP1700 LDO
  - [ ] TP4056 charger
  - [ ] N-channel MOSFET (for GPS power switching)
  - [ ] Voltage divider resistors (for battery monitoring)
  - [ ] Enclosure materials / 3D printer filament
  - [ ] Raspberry Pi Zero 2 W (for base station)
  - [ ] LoRa hat for Raspberry Pi (for base station)
- [ ] Design PCB or protoboard layout
- [ ] Design 3D-printed enclosure with silicone gasket groove
- [x] ~~Implement tracker firmware~~ → Mostly complete
- [ ] Implement base station Python script
- [ ] Implement Flask Web UI
- [ ] Set up HiveMQ broker
- [ ] Set up cloud backend (MQTT broker + database)

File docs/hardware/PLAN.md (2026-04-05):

# Pet Tracker Implementation Plan

## Overview

This plan outlines the implementation order for the ESP32-C6 pet tracker
firmware. The goal is to build incrementally, starting with bare metal hardware
access and adding complexity layer by layer.

---

## Phase 1: Project Scaffold

### 1.1 Initialize ESP-IDF C++ Project

```bash
# Create project with ESP-IDF
idf.py create-project pet-tracker
cd pet-tracker

# Configure for ESP32-C6
idf.py set-target esp32c6
idf.py menuconfig  # Configure JTAG, flash, etc.
```

### 1.2 Verify Build Pipeline

- [x] Build for ESP32-C6 target: `idf.py build`
- [x] Flash to device: `idf.py -p /dev/ttyACM0 flash monitor`
- [x] Verify basic "hello world" via `ESP_LOGI` output

**Done**: Build infrastructure validated via Docker (`build.sh`) and host tests.

### 1.3 Create Module Structure

```
firmware/
├── main/
│   ├── main.cpp             # Entry point
│   ├── lib.cpp              # Shared types (optional)
│   ├── gps.cpp              # GPS module
│   ├── nmea_parser.hpp      # Header-only NMEA parsing (testable)
│   ├── lora/
│   │   ├── sx1262.cpp
│   │   └── sx1262.hpp
│   ├── power.cpp            # Sleep/wake
│   ├── accelerometer.cpp    # LIS3DH I2C driver
│   ├── ble.cpp              # BLE GATT server
│   ├── geofence.cpp
│   ├── config.cpp           # NVS
│   └── error.cpp
└── tests/                   # Host-based unit tests with mocks
```

---

## Phase 2: Hardware Drivers

### 2.1 GPIO (Day 1)

**Goal**: Control LEDs, read button

```cpp
// gpio_driver.cpp
class GpioDriver {
public:
    static void init();
    static void set_led(bool state);
    static bool is_button_pressed();
};
```

- [x] **Done** - Implemented in `gpio_driver.cpp`

**Test**: LED blinks, button press detected

### 2.2 Power Management (Day 1–2)

**Goal**: Enter/exit deep sleep, configure RTC wake timer

```cpp
// deep_sleep.hpp
enum class WakeSource {
    Timer(uint32_t duration_ms),
    Button,
};

void enter_deep_sleep(WakeSource source);
WakeSource wake_reason();
uint16_t get_battery_voltage();  // mV via ADC
```

- [x] **Done** - Implemented in `deep_sleep.hpp`, merged PR #1

**Test**: Device sleeps for N seconds, wakes, reports wake reason

### 2.3 LED Driver (Day 1)

**Goal**: LED control with patterns

```cpp
// led_driver.cpp
class LedDriver {
public:
    static void init();
    static void set(bool on);
    static void blink(uint32_t interval_ms);
};
```

- [x] **Done** - Implemented in `led_driver.cpp`

### 2.4 Button Handler (Day 1)

**Goal**: Button debouncing

```cpp
// button_handler.cpp
class ButtonHandler {
public:
    ButtonHandler(gpio_num_t pin);
    void update();  // Call periodically
    bool was_pressed();  // Returns true once per press
};
```

- [x] **Done** - Implemented in `button_handler.cpp`, merged PR #3
- [x] **Bug Fixed**: Debounce bug (first press always failed) resolved by proper initialization to `-INT64_MAX`

**Test**: Button press detected, debounced correctly

### 2.5 Accelerometer LIS3DH (Day 2)

**Goal**: Motion detection via I2C, wake on movement

```cpp
// accelerometer.cpp
class Accelerometer {
public:
    esp_err_t init();
    esp_err_t enable_motion_interrupt(uint16_t threshold_mg);
    esp_err_t clear_interrupt();
    bool has_motion();
};
```

- [ ] **Pending** - Not yet implemented

**Test**: LIS3DH triggers interrupt on movement

### 2.6 GPS Module (Day 2–3)

**Goal**: Parse NMEA sentences, extract lat/lon/altitude

```cpp
// gps.cpp
class GpsDriver {
public:
    GpsDriver(gpio_num_t tx_pin, gpio_num_t rx_pin);
    void power_on();
    void power_off();
    GpsData read_fix(uint32_t timeout_ms);
};

// nmea_parser.hpp (header-only, testable on host)
struct GpsData {
    int32_t latitude;    // degrees * 1e6
    int32_t longitude;   // degrees * 1e6
    int32_t altitude;    // meters * 100 (cm)
    bool valid;
    uint32_t timestamp;
};

bool parse_nmea(const char* nmea, GpsData* out);
```

- [x] **Done** - Implemented in `gps.cpp` and `nmea_parser.hpp`, merged PR #2
- [x] **Updated** - Baud rate changed from 9600 to 115200 for M100-5883 compatibility
- [x] **Bugs Fixed**: NMEA sentence type detection (`nmea + 3`), field index offset, buffer size issues

**Test**:
- GPS powered on, receives NMEA on UART
- Fix extracted (timeout after 60s returns `valid: false`)

### 2.7 LoRa SX1262 (Day 3–5)

**Goal**: Initialize SX1262, send/receive packets

```cpp
// lora/sx1262.hpp
class LoRaDriver {
public:
    LoRaDriver();
    esp_err_t init();
    esp_err_t send(const RadioPacket& packet);
    esp_err_t recv(RadioPacket& packet, uint32_t timeout_ms);
    esp_err_t sleep();
    esp_err_t wake();
};
```

- [ ] **Pending** - Not yet implemented

**Test**:
- TX: Send packet, verify received on base station
- RX: Listen for packet with timeout
- Sleep: Verify low current draw

---

## Phase 3: State Machine

- [ ] **Pending** - Not yet implemented

### 3.1 Basic State Machine (Day 5–6)

Wake sources: RTC timer, LIS3DH motion interrupt, button press

```cpp
enum class State {
    DeepSleep,
    Idle,
    AcquiringGps,
    Transmitting,
};

void run_state_machine() {
    while (true) {
        switch (current_state) {
            case State::DeepSleep:
                wait_for_wake();
                current_state = State::Idle;
                break;
            case State::Idle:
                current_state = State::AcquiringGps;
                break;
            case State::AcquiringGps: {
                GpsData data = gps.read_fix(GPS_TIMEOUT_MS);
                current_state = State::Transmitting;
                break;
            }
            case State::Transmitting: {
                esp_err_t err = lora.send(data);
                if (err == ESP_OK) {
                    enter_deep_sleep(SLEEP_INTERVAL_MS);
                }
                break;
            }
        }
    }
}
```

### 3.2 Motion-Aware Sleep (Day 6)

When LIS3DH detects motion after stationary period, wake immediately.

```cpp
uint32_t determine_sleep_duration(bool is_moving) {
    if (is_moving) {
        return config.sleep_interval_ms;
    } else {
        return config.stationary_interval_ms;
    }
}
```

### 3.3 Retry Logic (Day 6)

- On TX failure: retry up to 3 times with exponential backoff
- On GPS timeout: transmit with `valid=false` flag set
- On TX failure + BLE in range: fallback to BLE notification

---

## Phase 4: Configuration & Storage

- [ ] **Pending** - Not yet implemented

### 4.1 NVS Configuration (Day 7)

```cpp
// config.hpp
struct TrackerConfig {
    uint32_t device_id;
    uint32_t sleep_interval_ms;
    uint32_t stationary_interval_ms;
    uint8_t tx_power;
    uint8_t sf;
};

esp_err_t load_config(TrackerConfig* out);
esp_err_t save_config(const TrackerConfig& config);
```

**Stored keys**:
- `device_id` (u32)
- `sleep_interval_ms` (u32)
- `stationary_interval_ms` (u32)
- `tx_power` (u8)
- `sf` (u8)

### 4.2 Geofence Storage (Day 7–8)

```cpp
struct Geofence {
    std::string name;
    ZoneType zone_type;  // Circle or Polygon
    int32_t center_lat;
    int32_t center_lon;
    uint32_t radius_m;  // for Circle
    std::vector<std::pair<int32_t, int32_t>> vertices;  // for Polygon
};

esp_err_t load_geofences(std::vector<Geofence>* out);
esp_err_t save_geofences(const std::vector<Geofence>& geofences);
```

---

## Phase 5: Geofencing

- [ ] **Pending** - Not yet implemented

### 5.1 Point-in-Circle (Day 8)

```cpp
bool check_geofence_circle(
    int32_t lat, int32_t lon,
    int32_t center_lat, int32_t center_lon,
    uint32_t radius_m
) {
    int64_t distance = haversine_distance(lat, lon, center_lat, center_lon);
    return distance <= radius_m;
}
```

### 5.2 Point-in-Polygon (Day 8–9)

Ray casting algorithm for polygon zones.

---

## Phase 6: Integration & Testing

### 6.1 Host-Based Unit Tests (In Progress)

- [x] NMEA parser tests (43 assertions, 5 test cases)
- [x] Button handler tests (4 assertions)
- [x] LED driver tests (9 assertions, 1 test case)
- [x] LoRa driver tests (14 assertions, 3 test cases)
- [ ] GPS driver tests
- [ ] Expand LoRa tests: packet TX/RX, error conditions, state transitions, timeouts

### 6.2 Target Tests

- [ ] Full cycle: wake → GPS fix → LoRa TX → deep sleep
- [ ] GPS timeout: wake → 60s no fix → TX with invalid flag → deep sleep
- [ ] TX failure: wake → GPS fix → TX fails → retry → success → deep sleep
- [ ] Button wake: wake immediately on button press
- [ ] Motion wake: LIS3DH triggers wake on movement
- [ ] Motion sleep: Device enters longer sleep interval when stationary
- [ ] BLE fallback: TX fails → BLE available → notify via BLE

### 6.3 Power Measurement

- [ ] Measure deep sleep current (target: <10µA including LIS3DH)
- [ ] Measure GPS acquisition current (target: ~25mA)
- [ ] Measure LoRa TX current (target: ~120mA)
- [ ] Measure LIS3DH low-power mode current (~3µA)
- [ ] Verify battery life estimate matches design

### 6.4 Range Test

- [ ] TX from 100m away, verify received
- [ ] TX from 1km away, verify received
- [ ] Find SF/range boundary

---

## Phase 7: Base Station (Python on Raspberry Pi)

### 7.1 Raspberry Pi Setup

```bash
# Install Python dependencies
pip install spidev paho-mqtt

# Configure WiFi and enable SPI
sudo raspi-config
```

### 7.2 LoRa Receiver (Python)

```python
# lora_receiver.py
import spidev
from sx1262 import SX1262

def main():
    lora = SX1262(spi_bus=0, spi_device=0)
    lora.receive_mode()

    while True:
        packet = lora.recv(timeout_ms=1000)
        if packet:
            parsed = parse_packet(packet)
            publish_to_mqtt(parsed)

def parse_packet(data):
    # Unpack 23-byte binary packet
    device_id, lat, lon, alt, battery, flags, ts = struct.unpack('<IiiIHBI', data)
    return {...}

def publish_to_mqtt(data):
    client = mqtt.Client()
    client.connect("hivemq-broker.local")
    client.publish(f"pettracker/{data['device_id']}/location", json.dumps(data))
```

### 7.3 MQTT Integration

- Connect to HiveMQ broker (configurable address)
- Publish location data to topic: `pettracker/{device_id}/location`
- Subscribe to commands: `pettracker/{device_id}/command`

### 7.4 Optional ACK

Send LoRa ACK back to tracker after successful MQTT publish.

### 7.5 Flask Web UI

```python
# app.py
from flask import Flask, jsonify, request, render_template
import sqlite3

app = Flask(__name__)

@app.route('/')
def index():
    return render_template('index.html')

@app.route('/api/devices')
def get_devices():
    # Return list of registered devices

@app.route('/api/devices/<device_id>/history')
def get_history(device_id):
    # Return location history from SQLite

@app.route('/api/config', methods=['GET', 'POST'])
def config():
    # Get/set WiFi, MQTT, LoRa settings

@app.route('/api/geofences', methods=['GET', 'POST', 'DELETE'])
def geofences():
    # Manage geofence zones
```

**Frontend files** (templates/):
- `templates/index.html` — Dashboard with Leaflet map
- `templates/device.html` — Device detail view
- `templates/config.html` — Configuration form
- `static/css/style.css` — Minimal styling
- `static/js/app.js` — Map updates, MQTT subscription

**Day 12**: Flask setup, basic routes, SQLite schema
**Day 13**: Frontend HTML/JS, Leaflet map integration
**Day 14**: MQTT live updates, geofence management UI

---

## Phase 12: PCB Design

### 12.1 KiCad Project Setup

- [ ] Create KiCad project in `hardware/tracker/`
- [ ] Configure project settings (board size, layers, clearance)
- [ ] Add symbol libraries for custom components

### 12.2 Component Footprints

- [ ] ESP32-C6-WROOM-1C module
- [ ] SX1262 LoRa module
- [ ] GPS module (u-blox NEO-6M or compatible)
- [ ] LIS3DH accelerometer
- [ ] MCP1700 LDO
- [ ] TP4056 LiPo charger
- [ ] N-channel MOSFET (AO3400 or similar)
- [ ] Passive components (resistors, capacitors)
- [ ] Connectors (JST-PH for battery, U.FL for antenna)

### 12.3 Schematic Entry

- [ ] Power tree: LiPo → MCP1700 → 3.3V rails
- [ ] ESP32-C6 minimum circuit (power, reset, boot)
- [ ] SX1262 SPI interface and antenna
- [ ] GPS UART interface
- [ ] LIS3DH I2C interface
- [ ] Battery voltage divider to ADC
- [ ] GPS power switch (MOSFET)
- [ ] LED and button circuits

### 12.4 PCB Layout

- [ ] Module placement (ESP32-C6, SX1262, GPS, LIS3DH)
- [ ] RF antenna considerations (SX1262 + GPS)
- [ ] Power plane and ground pour
- [ ] Decoupling capacitors near power pins
- [ ] UART/SPI trace routing
- [ ] Manufacturing DFM checks

### 12.5 Manufacturing

- [ ] Generate Gerber files
- [ ] Create drill files ( Excellon)
- [ ] Generate BOM (interactive HTML)
- [ ] Order PCB prototype (JLCPCB, PCBWay, etc.)
- [ ] Order components from BOM

### Deliverables

```
hardware/tracker/
├── tracker.pro           # KiCad project
├── tracker.sch          # Schematic
├── tracker.kicad_pcb    # PCB layout
├── bom/                  # Manufacturing files
│   ├── Gerber.zip
│   ├── drill_files.zip
│   └── BOM.csv
└── footprint/           # Custom footprints if needed
```

---

## Phase 13: Enclosure Design

### 13.1 CAD Model Setup

- [ ] Create FreeCAD/OpenSCAD project in `hardware/enclosure/`
- [ ] Import PCB dimensions from KiCad
- [ ] Add component heights (ESP32-C6 module, SX1262, GPS, LIS3DH, battery)

### 13.2 Mechanical Design

- [ ] Bottom case (holds PCB, battery)
- [ ] Top case (antenna clearance, LED window)
- [ ] Gasket groove (silicone gasket seal)
- [ ] Battery compartment
- [ ] Strap mounting holes

### 13.3 Antenna Considerations

- [ ] LoRa U.FL antenna placement
- [ ] GPS patch antenna clearance
- [ ] Ground plane requirements

### 13.4 Waterproofing

- [ ] Silicone gasket design (2mm x 5mm channel)
- [ ] Lens/LED window seal
- [ ] Charging port access (rubber plug)

### 13.5 3D Printing

- [ ] Test print fit with PCB
- [ ] Iterate on gasket groove
- [ ] Wall thickness optimization (2-3mm)
- [ ] Print settings: PETG 250°C, 20% infill

### Deliverables

```
hardware/enclosure/
├── case_bottom.fcstd    # FreeCAD file
├── case_top.fcstd
├── gasket.stl           # 3D printable gasket
└── print_settings/     # Slicer profiles
```

---

## Current Status

See [PROGRESS.md](../../PROGRESS.md) for current implementation status.

---

## TODO

- [x] Add Doxygen docstrings to all public APIs (LoRaDriver, Gps, ButtonHandler, LedDriver, etc.)
- [x] Add unit tests for LoRa driver with SPI mock
- [x] Expand LoRa driver tests: packet TX/RX, error conditions, state transitions, timeout scenarios
- [x] Add interrupt-driven DIO handling for LoRa (replace polling with FreeRTOS event group)

---

## Open Questions

All questions have been answered. See "Key Decisions Made" above.

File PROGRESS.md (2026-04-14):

# Project Progress

## Current Status

### Completed

- **Phase 1 & 2**: Integration fixes (PR #16 merged)
  - Added `gps.init()` and `lora.init()` calls
  - Made LED driver static and passed to state machine
  - Added `configure_wakeup_sources()` for GPIO wakeup
  - Fixed `get_wakeup_source()` to distinguish MOTION vs BUTTON
  - Fixed duplicate `esp_sleep_enable_gpio_wakeup()` calls
- **Phase 3**: Error handling (PR #17 merged)
  - `TrackerStateMachine::init()` now checks and propagates `Config::init()` and `Config::load()` errors
  - `Config::load()` returns `ESP_ERR_NOT_FOUND` when NVS is empty (all defaults used)
  - Config load log uses `ESP_LOGW` when all defaults used

### In Progress

- **Phase 4**: Integration (ButtonHandler, geofence, BLE notifications, last_wake tracking)
  - ✅ ButtonHandler integrated into state machine
  - ✅ Button wake now uses shorter sleep duration (`BUTTON_WAKE_SLEEP_MS`)
  - ✅ Button wakeup properly configured for deep sleep
  - ✅ `last_wake` now assigned and used
  - ✅ Geofence integration - location checked against zones after GPS fix
  - ✅ BLE alert sent on geofence breach

---

## Implementation Order Summary

| Phase | Module | Status |
|---|---|---|
| 1 | Project scaffold, CMake, Docker build | ✅ Done |
| 2 | Deep sleep, wake sources | ✅ Done (PR #1) |
| 2 | GPS UART driver, NMEA parsing | ✅ Done (PR #2) |
| 2 | Button handler with debounce | ✅ Done (bug fixed) |
| 2 | LED driver | ✅ Done |
| 3 | Unit tests with mocks | ✅ Done (PR #3, PR #7) |
| 4 | LoRa SX1262 driver | ✅ Done (PR #6, PR #7) |
| 4 | BLE GATT server | ✅ Done (PR #9) |
| 4 | LIS3DH accelerometer | ✅ Done (PR #10) |
| 5 | State machine | ✅ Done (PR #11) |
| 6 | NVS config storage | ✅ Done (PR #12) |
| 7 | Motion-aware sleep | ✅ Done (PR #11) |
| 8 | Geofencing | ✅ Done (PR #13, #14) |
| 9 | Integration testing | ✅ Done (PR #24) |
| 10 | Base station (Pi + Python/Flask) | ✅ Done (PR #31) |
| 11 | Flask Web UI | ✅ Done (PR #31) |
| 12 | PCB design | Pending |
| 13 | Enclosure design | Pending |

---

## Phase 4: Integration Details

### ButtonHandler Integration ✅

- **Status**: Integrated
- **Files**: `button_handler.cpp`, `button_handler.hpp`, `state_machine.cpp`
- **Changes**:
  - Added `ButtonHandler` member to `TrackerStateMachine`
  - Added `check_button()` method
  - Button now configured as deep sleep wakeup source

### Button Wakeup Configuration ✅

- **Status**: Fixed
- **Files**: `state_machine.cpp:configure_wakeup_sources()`
- **Changes**: Added `esp_sleep_enable_gpio_wakeup()` call
- **Note**: Button uses `gpio_wakeup_enable()` with `GPIO_INTR_LOW_LEVEL`

### Geofence Integration ✅

- **Status**: Complete
- **Files**: `geofence.cpp`, `geofence.hpp`, `config.hpp`, `state_machine.cpp`
- **Changes**:
  - Added zone storage to `TrackerConfig` (up to 4 zones)
  - Zones persisted to/from NVS via config save/load
  - `check_geofence()` called after GPS fix
  - Breach triggers BLE alert and sets `is_moving = true`
  - Default "Home" zone created if no zones configured

### BLE Notifications ✅

- **Status**: Complete
- **Files**: `ble.hpp`, `ble.cpp`, `state_machine.cpp`
- **Changes**:
  - Added `BleAlertData` struct with alert type, zone index, location, timestamp
  - Added `BLE_CHAR_ALERT_UUID` (0x2A06) for alert characteristic
  - Added `send_alert()` method using `esp_ble_gatts_send_indicate()`
  - Alert sent on geofence breach to connected device

### last_wake Tracking ✅

- **Status**: Fixed
- **Changes**: 
  - `last_wake` now assigned from `get_wake_source()` result
  - `get_sleep_duration()` uses `BUTTON_WAKE_SLEEP_MS` when last_wake was BUTTON

### Battery Reading

- **Status**: ✅ Implemented (PR #25 merged)
- **Files**: `battery.hpp`, `battery.cpp`
- **Features**:
  - ADC voltage reading with voltage divider calculation
  - Percentage calculation (3000mV empty → 4200mV full)
  - Integrated into state machine `try_lora_send()` for transmission
  - GPS power switching via MOSFET

### Base Station (Python/Flask)

- **Status**: ✅ Implemented (PR #31 merged)
- **Files**: `base_station/`
- **Components**:
  - `config.py` - Configuration dataclasses (MQTT, LoRa, server, DB)
  - `packet_parser.py` - Parse 23-byte tracker packet format
  - `mqtt_client.py` - MQTT client for HiveMQ integration
  - `database.py` - SQLite storage for devices and locations
  - `app.py` - Flask web application with REST API
  - `templates/index.html` - Dashboard with device list
  - `static/` - CSS and JS for web UI
- **API Endpoints**:
  - `GET /` - Dashboard
  - `GET /api/devices` - List devices
  - `GET /api/devices/<id>` - Device details
  - `POST /api/devices/<id>/name` - Update device name

---

## Codebase Analysis (2026-04-14)

### Overall Health: 8/10 - Functional firmware, base station complete

### Code Quality Assessment

| Aspect | Rating | Notes |
|---|---|---|
| Code Organization | 8/10 | Clean separation, follows ESP-IDF patterns |
| Feature Completeness | 8/10 | Core firmware and base station complete |
| Error Handling | 8/10 | Proper error returns, BLE bugs fixed |
| Testing | 8/10 | Good host test coverage + integration tests |
| Documentation | 8/10 | Good README/PROGRESS, DESIGN.md updated |
| Build System | 8/10 | Clean Docker setup, good CI |
| Code Quality | 8/10 | BLE bugs fixed, no critical issues |

### Missing/Incomplete

| Item | Phase | Priority |
|---|---|---|
| PCB design | 12 | Medium |
| Enclosure design | 13 | Low |

### Recommended Next Steps

1. ~~Fix critical BLE bugs~~ - ✅ Done (PR #23 merged)
2. ~~Phase 9: Integration testing~~ - ✅ Done (PR #24 merged)
3. ~~GPS power switching~~ - ✅ Done (PR #25 merged)
4. ~~Battery ADC reading~~ - ✅ Done (PR #25 merged)
5. ~~Phase 10: Base station~~ - ✅ Done (PR #31 merged)
6. **PCB design** - Begin KiCad layout

---

## Key Decisions Made

- **ESP-IDF version**: v6.0
- **Target MCU**: ESP32-C6 (RISC-V)
- **LoRa driver**: Custom SX1262 driver (SPI interface)
- **GPS parsing**: Custom header-only NMEA parser (`nmea_parser.hpp`)
- **GPS module**: HGLRC M100-5883 (M10, 10Hz, 115200 baud, 72ch, multi-GNSS)
- **LoRa frequency**: 915 MHz (US region)
- **BLE fallback**: Included for direct phone connectivity when in range
- **Accelerometer**: LIS3DH for motion detection (wake on movement)
- **Base station**: Python on Raspberry Pi with LoRa hat
- **MQTT broker**: HiveMQ (self-hosted)
- **WiFi config**: AP mode on base station for easy configuration
- **Waterproofing**: Silicone gasket between case halves
- **Testing**: Host-based unit tests with mocked ESP-IDF headers

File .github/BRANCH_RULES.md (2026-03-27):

# Branch Protection Rules

## Main Branch (`main`)

### Protection Settings

| Setting | Value | Notes |
|---|---|---|
| Require pull requests | ✅ Enabled | All changes must go through PR |
| Require approvals | ✅ 1 required | Human review required for agent changes |
| Dismiss stale reviews | ✅ Enabled | Auto-dismiss when new commits pushed |
| Require status checks | ✅ All CI jobs | build-firmware, host-tests, lint-* |
| Require linear history | ❌ Disabled | Keep merge commits for clarity |
| Allow force pushes | ❌ Disabled | No force pushes to main |

### Why These Rules?

- **Pull requests**: Ensures all changes are reviewed, even quick fixes
- **1 approval**: Single developer can still merge, but must consciously approve
- **Status checks**: CI must pass before merge - catches build errors
- **No force push**: Protects history integrity

## Feature Branches

| Setting | Value |
|---|---|
| Require pull requests | ✅ Enabled |
| Require approvals | ❌ Disabled |
| Require status checks | ❌ Disabled |
| Allow force pushes | ✅ Enabled |

Feature branches are for work-in-progress. They can be force-pushed freely and don't require approval.

## Agent (OpenCode) Branches

When the agent creates branches:
- Branch name format: `feature/*`, `fix/*`, `hotfix/*`
- Agent must create PR after CI passes
- Agent must wait for human approval before merge
- Agent should never merge its own PRs

## Manual Setup Required

Branch protection rules must be set via GitHub UI or terraform:

1. Go to **Settings → Branches → Add rule**
2. Enter `main` as branch name pattern
3. Enable the settings listed above
4. Under "Protect matching branches" → select required status checks:
   - `CI / build-firmware`
   - `CI / host-tests`
   - `CI / lint-cpp`
   - `CI / lint-markdown`

## Emergency Overrides

If you need to bypass protection (emergency hotfix):
1. Use GitHub UI → "Bypass branch protection" (requires admin rights)
2. This should rarely be needed

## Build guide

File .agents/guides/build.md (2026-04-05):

# Build Guide

## ESP-IDF Installation

### Host Installation (Recommended for Development)

1. **Install ESP-IDF v6.0**:

   **Option A: Using the offline installer** (installed to `~/.espressif/`):

   ```bash
   # The installer typically places ESP-IDF at ~/.espressif/v6.0/esp-idf
   ```

   **Option B: Manual git clone** (to `~/esp-idf`):

   ```bash
   mkdir -p ~/esp-idf
   cd ~/esp-idf
   git clone --depth 1 --branch v6.0 --recursive https://github.com/espressif/esp-idf.git
   cd esp-idf
   ./install.sh
   ```

2. **Activate ESP-IDF environment** (run once per terminal session):

   ```bash
   . ~/.espressif/v6.0/esp-idf/export.sh
   # OR if using manual install:
   . ~/esp-idf/export.sh
   ```

   Or add to your shell profile for convenience:

   ```bash
   # Add to ~/.bashrc or ~/.zshrc
   alias ef='. ~/.espressif/v6.0/esp-idf/export.sh'
   ```

3. **Verify installation**:

   ```bash
   idf.py --version  # Should show v6.0.x
   ```

### Docker Installation (Alternative)

```bash
docker pull espressif/idf:v6.0
```

---

## Building

### Host Build (Recommended)

```bash
cd firmware
idf.py set-target esp32s3    # Set target once (or esp32c6)
idf.py build                  # Build
idf.py -p /dev/ttyACM0 flash monitor  # Flash and monitor
```

### Docker Build

```bash
cd firmware
./build.sh                    # Build for ESP32S3 (default)
./build.sh --board esp32c6    # Build for ESP32C6
./build.sh --flash --monitor  # Build, flash, and monitor
```

## Flash to Device

### Host Flash

```bash
idf.py -p /dev/ttyACM0 flash monitor
```

### Docker Flash

```bash
docker run --rm -v $(pwd):/workspace -w /workspace espressif/idf:v6.0 \
  sh -c ". /opt/esp/idf/export.sh && idf.py -D IDF_TARGET=esp32s3 -p /dev/ttyACM0 flash monitor"
```

## CI Build Notes

The CI builds for **both ESP32S3 and ESP32C6 targets**:
- Always test locally for your target first
- If CI fails with target mismatch, run `rm -rf build sdkconfig` locally and rebuild
- When adding ESP-IDF APIs, verify the API exists in ESP-IDF v6.0 for both architectures

## Code Formatting

### C++ Code

- **Config**: `.clang-format` (GNU style, 4-space tabs, 100 char line length)
- **Format files**: `clang-format -i <files>`
- **Pre-commit**: Auto-formats staged C++ files
- **CI check**: Non-blocking (ESP-IDF conventions differ from LLVM style)

### Markdown

- **Line length**: 120 characters
- **Lint**: `markdownlint-cli2 "**/*.md"`
- **Pre-commit**: Auto-lints staged Markdown files

### Pre-commit Hooks

Install once:

```bash
pip install pre-commit
pre-commit install
```

Pre-commit runs automatically on `git commit`. To run manually:

```bash
pre-commit run --all-files
```

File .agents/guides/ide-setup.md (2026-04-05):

# IDE Setup Guide

This guide covers IDE configuration for ESP32 firmware development.

## VS Code Extensions

### Required

- **ESP-IDF** (Espressif) - Official ESP-IDF extension
- **clangd** (llvm) - C++ language server (recommended over C/C++ extension)

### Recommended

- **Markdownlint** (David Anson) - Markdown linting
- **pre-commit** (pre-commit) - Pre-commit hook integration

## clangd Configuration

### Setup

1. **Build project first** to generate `compile_commands.json`:

   ```bash
   cd firmware
   ./build.sh
   ```

2. **clangd config** at `.clangd/config.yaml`:

   ```yaml
   CompileFlags:
     CompilationDatabase: firmware/build
     Remove:
       - "-mlongcalls"
       - "-fno-shrink-wrap"
       - "-fstrict-volatile-bitfields"
   ```

3. **Reload VS Code** to apply changes

### Expected LSP Warnings

You will see warnings like:

```
Unknown argument '-mlongcalls'; did you mean '-mlong-calls'?
Unknown argument: '-fno-shrink-wrap'
'driver/uart.h' file not found
```

**These are safe to ignore** because:

- ESP-IDF uses `xtensa-esp-elf-gcc` (not host GCC)
- Xtensa-specific flags are valid for ESP32 compilation
- Host LSP uses standard GCC which doesn't recognize these flags
- Actual builds work correctly

### Troubleshooting

**"Unknown argument" warnings**
- Expected for ESP-IDF code
- Safe to ignore - builds work correctly

**Missing ESP-IDF headers**
- Rebuild project: `./build.sh`
- Ensure `compile_commands.json` exists in `firmware/build/`

**Target mismatch errors**
- Clean and rebuild: `rm -rf firmware/build firmware/sdkconfig`
- Rebuild: `./build.sh`

## Code Formatting

### C++ Code

**Automatic** (via pre-commit):
- Staged files auto-formatted on commit
- GNU style (4-space tabs, 100 char line length)

**Manual**:

```bash
# Format specific files
clang-format -i firmware/main/main.cpp

# Format all firmware files
find firmware/main -type f \( -name '*.cpp' -o -name '*.hpp' \) | xargs clang-format -i
```

### Markdown

**Automatic** (via pre-commit):
- Staged files auto-linted on commit
- 120 character line length

**Manual**:

```bash
# Lint all markdown
markdownlint-cli2 "**/*.md" \
  "!firmware/tests/build/**" \
  "!firmware/build/**" \
  "!third_party/**" \
  "!docs/plans/**" \
  "!.opencode/**"
```

## Pre-commit Hooks

### Installation

```bash
# Install pre-commit
pip install pre-commit

# Install git hooks
pre-commit install
```

### What it checks

| Hook | Files | Action |
|---|---|---|
| `clang-format` | `.cpp`, `.hpp`, `.c`, `.h` | Auto-format |
| `markdownlint-cli2` | `.md` | Lint (blocks commit on error) |
| `shellcheck` | `.sh` | Lint (blocks commit on error) |
| `trailing-whitespace` | All | Auto-fix |
| `end-of-file-fixer` | All | Auto-fix |

### Manual run

```bash
# Run on all files
pre-commit run --all-files

# Run on staged files only
pre-commit run
```

### Skip hooks (emergency only)

```bash
git commit --no-verify -m "message"
```

**Note**: Only skip if absolutely necessary. Fix issues properly when possible.

## ESP-IDF Extension

### Configuration

1. **Select ESP-IDF version**: v6.0 (per `sdkconfig.defaults`)
2. **Set target**: ESP32-S3 or ESP32-C6
3. **Python virtualenv**: Let extension manage automatically

### Build & Flash

```bash
# Build
idf.py build

# Flash and monitor
idf.py -p /dev/ttyACM0 flash monitor

# Using Docker (recommended)
cd firmware
./build.sh --flash --monitor
```

## Recommended Settings

### VS Code `settings.json`

```json
{
  "editor.formatOnSave": true,
  "editor.defaultFormatter": "llvm-vs-code-extensions.vscode-clangd",
  "clangd.path": "clangd",
  "markdownlint.config": {
    "default": true,
    "MD013": { "line_length": 120 }
  }
}
```

## Resources

- [ESP-IDF Documentation](https://docs.espressif.com/projects/esp-idf/en/stable/)
- [clangd Configuration](https://clangd.llvm.org/config.html)
- [pre-commit Hooks](https://pre-commit.com/)

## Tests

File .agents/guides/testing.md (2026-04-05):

# Testing Guide

## Host-Based Unit Tests

Host tests run on Linux without hardware, using mocked ESP-IDF headers.

```bash
cd firmware/tests
mkdir -p build && cd build
cmake .. && make -j$(nproc)
./test_nmea_parser    # NMEA parsing tests
./test_button_handler # Button debounce tests
./test_led_driver    # LED driver tests
./test_lora_driver    # LoRa driver tests
./test_geofence       # Geofence tests
```

## Target Tests

```bash
cd firmware
idf.py build
idf.py test
```

## Adding New Host Tests

1. **Create mock headers** in `tests/include/` if new ESP-IDF dependencies are needed
2. **Implement mock functions** in `tests/src/` following the existing pattern
3. **Add test file** following Catch2 TEST_CASE/SECTION format
4. **Update CMakeLists.txt** to include new test executable

## Mock Maintenance

| If you add... | Update these files |
|---|---|
| `esp_timer_get_time()` | `tests/include/esp_timer.h`, `tests/src/esp_timer_mock.cpp` |
| `gpio_get_level()` | `tests/include/driver/gpio.h`, `tests/src/gpio_mock.cpp` |
| `gpio_install_isr_service()` | `tests/include/driver/gpio.h`, `tests/src/gpio_mock.cpp` |
| `ESP_ERROR_CHECK()` | `tests/include/esp_err.h` |
| `ESP_LOG*` macros | `tests/include/esp_log.h` |
| `vEventGroupDelete()` | `tests/include/freertos/event_groups.h`, `tests/src/event_groups_mock.cpp` |
| `xEventGroupWaitBits()` | `tests/include/freertos/event_groups.h`, `tests/src/event_groups_mock.cpp` |

**Key principle**: Keep mocks minimal - only mock what the code actually calls. Prefer thin
wrappers around source files rather than comprehensive mocks.

**When adding new mocks:**

1. Check if mock already exists in `tests/include/` or `tests/src/`
2. Add declaration to mock header in `tests/include/`
3. Implement mock function in `tests/src/`
4. Update this table for future reference

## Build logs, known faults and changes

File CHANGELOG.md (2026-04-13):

# Changelog

All notable changes to this project will be documented in this file.

The format is based on [Keep a Changelog](https://keepachangelog.com/en/1.1.0/).

## [Unreleased]

### Added

- `.clang-format` configuration for GNU-style C++ formatting (ESP-IDF conventions)
- `.clangd/config.yaml` for clangd LSP configuration
- `.agents/guides/ide-setup.md` - Comprehensive IDE setup guide
- Pre-commit hooks for clang-format and markdownlint
- `PROGRESS.md` - Consolidated implementation status tracking
- Geofence zones storage in config (up to 4 zones)
- BLE alert characteristic for geofence breach notifications
- State machine diagram in `docs/firmware/STATE_MACHINE.md`

### Changed

- Markdown line length limit: 200 → 120 characters
- Updated `.pre-commit-config.yaml` with clang-format hook

### Fixed

- Removed duplicate `app_main()` causing linker errors
- Fixed ESP32-S3 pin conflict (LED and LoRa NSS both on GPIO_8)
- Fixed ESP32C6 pin conflict (ACCEL SDA and LoRa RESET both on GPIO_1)
- Added missing `gpio_install_isr_service()` initialization
- Added missing `i2c_driver_install()` for accelerometer
- Fixed event group memory leak in LoRaDriver destructor
- Fixed duplicate SX1262 command definitions
- Fixed GPS buffer overflow check
- Fixed integer overflow in accelerometer threshold calculation
- Fixed geofence test expectation for small radius zones
- Added missing mocks: `vEventGroupDelete()`, `gpio_install_isr_service()`
- Phase 3: `TrackerStateMachine::init()` now propagates errors from `Config::init()` and `Config::load()`
- Phase 4: ButtonHandler integrated into state machine
- Phase 4: Button wake now uses shorter sleep duration
- Phase 4: `last_wake` now assigned and used for sleep duration decisions
- Phase 4: Geofence integration - location checked against zones after GPS fix
- Phase 4: BLE alert sent on geofence breach
- Renamed project to LoRaPaws32

## [0.2.0] - 2025-04-05

### Added

- State machine for tracker lifecycle management with motion-aware sleep
- Pin configuration documentation in `hardware/tracker/PIN_MAPPING.md`
- Programmatic PCB builder script
- ESP-IDF v6.0 support for ESP32-S3 and ESP32-C6

### Changed

- Refactored main.cpp to use state machine pattern
- Updated board pin mappings for both ESP32-S3 and ESP32-C6 targets

## [0.1.0] - 2025-03-25

### Added

- Initial project structure
- GPS driver with NMEA parsing
- LoRa driver (SX1262) with basic transmission
- LED and button drivers
- Accelerometer driver (LIS3DH)
- Geofencing module with circle zone support
- BLE fallback support
- Deep sleep with timer and GPIO wakeup
- Host-based unit tests (NMEA parser, button handler, LED driver, LoRa driver, geofence)
- KiCad PCB design files for tracker and base station
- Flask web UI for base station
- CI/CD workflows

[Unreleased]: https://github.com/glennmcewan/esp32-tracker/compare/v0.2.0...HEAD
[0.2.0]: https://github.com/glennmcewan/esp32-tracker/compare/v0.1.0...v0.2.0
[0.1.0]: https://github.com/glennmcewan/esp32-tracker/releases/tag/v0.1.0

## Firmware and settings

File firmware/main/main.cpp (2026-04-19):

/**
 * @file main.cpp
 * @brief ESP32 Pet Tracker application entry point
 *
 * Pet tracker firmware that:
 * - Acquires GPS location via UART
 * - Transmits location data over LoRa SX1262
 * - Supports deep sleep between transmissions
 * - Button press to toggle LED and trigger transmission
 */

#include "driver/gpio.h"
#include "esp_log.h"
#include "esp_sleep.h"
#include "esp_timer.h"
#include "freertos/FreeRTOS.h"
#include "freertos/task.h"
#include <stdio.h>

#include "accelerometer.hpp"
#include "battery.hpp"
#include "board_config.h"
#include "button_handler.hpp"
#include "deep_sleep.hpp"
#include "gpio_driver.hpp"
#include "gps.hpp"
#include "led_driver.hpp"
#include "lora/sx1262.hpp"
#include "state_machine.hpp"

static const char* TAG = "pet-tracker";

extern "C" void
app_main (void) {
	ESP_LOGI (TAG, "Starting pet tracker...");

	static LedDriver led (BOARD_LED_PIN);

	static Gps gps (UART_NUM_1);
	esp_err_t gps_err = gps.init ();
	if (gps_err != ESP_OK) {
		ESP_LOGE (TAG, "GPS init failed: %s", esp_err_to_name (gps_err));
	}

	static LoRaDriver lora (spi_host_device_t::SPI2_HOST, BOARD_LORA_MOSI_PIN, BOARD_LORA_MISO_PIN,
							BOARD_LORA_SCK_PIN, BOARD_LORA_NSS_PIN, BOARD_LORA_RESET_PIN,
							BOARD_LORA_BUSY_PIN, BOARD_LORA_DIO1_PIN);
	ESP_ERROR_CHECK (lora.init ());

	static Accelerometer accel (I2C_NUM_0, BOARD_ACCEL_INT_PIN);
	esp_err_t accel_err = accel.init ();
	if (accel_err != ESP_OK) {
		ESP_LOGE (TAG, "Accelerometer init failed: %s", esp_err_to_name (accel_err));
	}
	ESP_ERROR_CHECK (accel.enable_motion_interrupt (2000));

	static BleServer ble;
	ESP_ERROR_CHECK (ble.init ());
	ESP_ERROR_CHECK (ble.start ());

	static BatteryDriver battery;
	esp_err_t battery_err = battery.init ();
	if (battery_err != ESP_OK) {
		ESP_LOGE (TAG, "Battery init failed: %s", esp_err_to_name (battery_err));
	}

	static TrackerStateMachine state_machine (gps, lora, accel, ble, led, battery);
	esp_err_t sm_err = state_machine.init ();
	if (sm_err != ESP_OK) {
		ESP_LOGE (TAG, "State machine init failed: %s", esp_err_to_name (sm_err));
	}

	ESP_LOGI (TAG, "Pet tracker initialized, entering main loop");

	while (true) {
		state_machine.run ();
		vTaskDelay (pdMS_TO_TICKS (1000));
	}
}

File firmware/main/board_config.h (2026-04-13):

#pragma once

/**
 * @brief Board pin configuration for ESP32-S3 and ESP32-C6
 *
 * Pin assignments for:
 * - Status LED
 * - Push button
 * - GPS UART (TX/RX)
 * - LoRa SX1262 SPI (MOSI/MISO/SCK/NSS/RESET/BUSY/DIO1)
 */

#include <sdkconfig.h>

#if defined(CONFIG_IDF_TARGET_ESP32S3)
#include <driver/gpio.h>

/** @brief Status LED GPIO */
#define BOARD_LED_PIN GPIO_NUM_40
/** @brief Push button GPIO (active-low, pulled high internally) */
#define BOARD_BUTTON_PIN GPIO_NUM_9
/** @brief GPS UART TX GPIO */
#define BOARD_GPS_TX_PIN GPIO_NUM_7
/** @brief GPS UART RX GPIO */
#define BOARD_GPS_RX_PIN GPIO_NUM_15
/** @brief GPS power control GPIO (active-high MOSFET) */
#define BOARD_GPS_POWER_PIN GPIO_NUM_21
/** @brief LoRa MOSI GPIO */
#define BOARD_LORA_MOSI_PIN GPIO_NUM_4
/** @brief LoRa MISO GPIO */
#define BOARD_LORA_MISO_PIN GPIO_NUM_5
/** @brief LoRa SCK GPIO */
#define BOARD_LORA_SCK_PIN GPIO_NUM_6
/** @brief LoRa NSS (chip select) GPIO */
#define BOARD_LORA_NSS_PIN GPIO_NUM_8
/** @brief LoRa reset GPIO */
#define BOARD_LORA_RESET_PIN GPIO_NUM_1
/** @brief LoRa busy indicator GPIO */
#define BOARD_LORA_BUSY_PIN GPIO_NUM_2
/** @brief LoRa DIO1 interrupt GPIO */
#define BOARD_LORA_DIO1_PIN GPIO_NUM_3
/** @brief LIS3DH interrupt GPIO */
#define BOARD_ACCEL_INT_PIN GPIO_NUM_0
/** @brief LIS3DH I2C SDA GPIO */
#define BOARD_ACCEL_SDA_PIN GPIO_NUM_11
/** @brief LIS3DH I2C SCL GPIO */
#define BOARD_ACCEL_SCL_PIN GPIO_NUM_12
/** @brief Battery voltage ADC GPIO (100k/100k divider) */
#define BOARD_BATTERY_ADC_PIN GPIO_NUM_1

#elif defined(CONFIG_IDF_TARGET_ESP32C6)
#include <driver/gpio.h>

/** @brief Status LED GPIO */
#define BOARD_LED_PIN		 GPIO_NUM_8
/** @brief Push button GPIO (active-low, pulled high internally) */
#define BOARD_BUTTON_PIN	 GPIO_NUM_9
/** @brief GPS UART TX GPIO */
#define BOARD_GPS_TX_PIN	 GPIO_NUM_4
/** @brief GPS UART RX GPIO */
#define BOARD_GPS_RX_PIN	 GPIO_NUM_5
/** @brief GPS power control GPIO (active-high MOSFET) */
#define BOARD_GPS_POWER_PIN	 GPIO_NUM_18
/** @brief LoRa MOSI GPIO */
#define BOARD_LORA_MOSI_PIN	 GPIO_NUM_6
/** @brief LoRa MISO GPIO */
#define BOARD_LORA_MISO_PIN	 GPIO_NUM_7
/** @brief LoRa SCK GPIO */
#define BOARD_LORA_SCK_PIN	 GPIO_NUM_8
/** @brief LoRa NSS (chip select) GPIO */
#define BOARD_LORA_NSS_PIN	 GPIO_NUM_10
/** @brief LoRa reset GPIO */
#define BOARD_LORA_RESET_PIN GPIO_NUM_11
/** @brief LoRa busy indicator GPIO */
#define BOARD_LORA_BUSY_PIN	 GPIO_NUM_3
/** @brief LoRa DIO1 interrupt GPIO */
#define BOARD_LORA_DIO1_PIN	 GPIO_NUM_1
/** @brief LIS3DH interrupt GPIO */
#define BOARD_ACCEL_INT_PIN	 GPIO_NUM_12
/** @brief LIS3DH I2C SDA GPIO */
#define BOARD_ACCEL_SDA_PIN	 GPIO_NUM_13
/** @brief LIS3DH I2C SCL GPIO */
#define BOARD_ACCEL_SCL_PIN	 GPIO_NUM_14

#else
#error "No target board specified. Set CONFIG_IDF_TARGET_ESP32S3 or CONFIG_IDF_TARGET_ESP32C6"
#endif

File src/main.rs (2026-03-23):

#![no_std]
#![no_main]

use esp_hal::clock::CpuClock;
use esp_hal::main;
use esp_hal::time::{Duration, Instant};

mod lib;

use lib::{Gpio, Led};

#[panic_handler]
fn panic(_: &core::panic::PanicInfo) -> ! {
    loop {}
}

esp_bootloader_esp_idf::esp_app_desc!();

#[main]
fn main() -> ! {
    let config = esp_hal::Config::default().with_cpu_clock(CpuClock::max());
    let peripherals = esp_hal::init(config);

    let mut led = Led::new(peripherals.GPIO48);
    let gpio = Gpio::new(peripherals.GPIO0);

    led.off();
    let mut led_state = false;

    loop {
        if gpio.is_button_pressed() {
            led_state = !led_state;
            if led_state {
                led.on();
            } else {
                led.off();
            }
        }

        let delay_start = Instant::now();
        while delay_start.elapsed() < Duration::from_millis(50) {}
    }
}

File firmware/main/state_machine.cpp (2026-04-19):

#include "state_machine.hpp"
#include "board_config.h"
#include "deep_sleep.hpp"
#include "driver/gpio.h"
#include "esp_log.h"
#include "esp_sleep.h"
#include "esp_timer.h"
#include "freertos/task.h"
#include <string.h>

static const char* TAG = "tracker";

TrackerStateMachine::TrackerStateMachine (Gps& gps, LoRaDriver& lora, Accelerometer& accel,
										  BleServer& ble, LedDriver& led, BatteryDriver& battery)
	: ctx_ ({ TrackerState::INIT, WakeSource::NONE, 0, false, false, 0, 0 }), gps_ (gps),
	  lora_ (lora), accel_ (accel), ble_ (ble), led_ (led), battery_ (battery),
	  geofence_breach_ (false) {}

esp_err_t
TrackerStateMachine::init () {
	esp_err_t err = Config::init ();
	if (err != ESP_OK) {
		ESP_LOGE (TAG, "Config::init() failed: %s", esp_err_to_name (err));
		transition_to (TrackerState::ERROR);
		return err;
	}

	err = Config::load (config_);
	if (err != ESP_OK) {
		ESP_LOGW (TAG, "Config::load() failed: %s, using defaults", esp_err_to_name (err));
	}

	lora_.set_tx_power (config_.tx_power);
	lora_.set_spreading_factor (config_.spreading_factor);

	transition_to (TrackerState::IDLE);
	return ESP_OK;
}

void
TrackerStateMachine::run () {
	while (true) {
		switch (ctx_.state) {
		case TrackerState::INIT:
			transition_to (TrackerState::IDLE);
			break;

		case TrackerState::IDLE:
			update_activity_time ();
			transition_to (TrackerState::ACQUIRING_GPS);
			break;

		case TrackerState::ACQUIRING_GPS: {
			gps_.power_on ();
			int64_t start_time = esp_timer_get_time () / 1000;
			bool timeout = false;

			while (!ctx_.gps_fix_obtained && !timeout) {
				if (gps_.update ()) {
					if (gps_.has_fix ()) {
						ctx_.gps_fix_obtained = true;
						ESP_LOGI (TAG, "GPS fix obtained");
						check_geofence ();
						break;
					}
				}

				int64_t elapsed = (esp_timer_get_time () / 1000) - start_time;
				if (elapsed > GPS_TIMEOUT_MS) {
					timeout = true;
					ESP_LOGW (TAG, "GPS timeout after %ums", GPS_TIMEOUT_MS);
				}

				vTaskDelay (pdMS_TO_TICKS (100));
			}

			gps_.power_off ();
			transition_to (TrackerState::TRANSMITTING);
			break;
		}

		case TrackerState::TRANSMITTING: {
			const auto& data = gps_.get_data ();
			if (ctx_.gps_fix_obtained) {
				ESP_LOGI (TAG, "TX: lat=%.6f, lon=%.6f, alt=%.1f", data.latitude, data.longitude,
						  data.altitude);
			} else {
				ESP_LOGI (TAG, "TX: no GPS fix, will send invalid");
			}

			esp_err_t err = transmit_location ();
			if (err != ESP_OK) {
				ESP_LOGE (TAG, "TX failed after retries, entering error state");
				transition_to (TrackerState::ERROR);
			} else {
				transition_to (TrackerState::DEEP_SLEEP);
			}
			break;
		}

		case TrackerState::DEEP_SLEEP: {
			uint32_t sleep_ms = get_sleep_duration ();
			ESP_LOGI (TAG, "Entering deep sleep for %u ms (moving=%s)", sleep_ms,
					  ctx_.is_moving ? "yes" : "no");

			check_motion ();
			configure_wakeup_sources ();

			lora_.sleep ();
			sleep (sleep_ms);

			WakeSource wake = get_wake_source ();
			ctx_.last_wake = wake;
			ESP_LOGI (TAG, "Woke up from: %s",
					  wake == WakeSource::TIMER	   ? "timer"
					  : wake == WakeSource::BUTTON ? "button"
					  : wake == WakeSource::MOTION ? "motion"
												   : "unknown");

			if (wake == WakeSource::MOTION) {
				ctx_.is_moving = true;
			} else if (wake == WakeSource::TIMER) {
				ctx_.is_moving = false;
			}

			ctx_.wake_count++;
			ctx_.gps_fix_obtained = false;
			ctx_.tx_retry_count = 0;
			geofence_breach_ = false;
			update_activity_time ();

			lora_.wake ();
			transition_to (TrackerState::IDLE);
			break;
		}

		case TrackerState::ERROR:
			ESP_LOGE (TAG, "Error state, resetting...");
			lora_.sleep ();
			sleep (config_.stationary_interval_ms);
			lora_.wake ();
			ctx_.tx_retry_count = 0;
			transition_to (TrackerState::IDLE);
			break;
		}
	}
}

void
TrackerStateMachine::transition_to (TrackerState new_state) {
	ctx_.state = new_state;
	ESP_LOGD (TAG, "State -> %s",
			  ctx_.state == TrackerState::INIT			  ? "INIT"
			  : ctx_.state == TrackerState::IDLE		  ? "IDLE"
			  : ctx_.state == TrackerState::ACQUIRING_GPS ? "ACQUIRING_GPS"
			  : ctx_.state == TrackerState::TRANSMITTING  ? "TRANSMITTING"
			  : ctx_.state == TrackerState::DEEP_SLEEP	  ? "DEEP_SLEEP"
														  : "ERROR");
}

WakeSource
TrackerStateMachine::get_wake_source () {
	uint64_t causes = esp_sleep_get_wakeup_causes ();
	if (causes & ESP_SLEEP_WAKEUP_TIMER) {
		return WakeSource::TIMER;
	} else if (causes & ESP_SLEEP_WAKEUP_GPIO) {
		if (gpio_get_level (BOARD_ACCEL_INT_PIN) == 1) {
			return WakeSource::MOTION;
		}
		return WakeSource::BUTTON;
	}
	return WakeSource::NONE;
}

void
TrackerStateMachine::sleep (uint32_t duration_ms) {
	DeepSleep::enable_timer_wakeup (duration_ms * 1000ULL);
	DeepSleep::sleep ();
}

void
TrackerStateMachine::configure_wakeup_sources () {
	gpio_wakeup_enable (BOARD_BUTTON_PIN, GPIO_INTR_LOW_LEVEL);
	esp_sleep_enable_gpio_wakeup ();
	accel_.enable_wakeup (BOARD_ACCEL_INT_PIN);
}

void
TrackerStateMachine::check_motion () {
	if (accel_.has_motion ()) {
		ctx_.is_moving = true;
		accel_.clear_interrupt ();
		ESP_LOGD (TAG, "Motion detected");
	} else {
		int64_t now = esp_timer_get_time () / 1000;
		if (now - ctx_.last_activity_time > INACTIVITY_THRESHOLD_MS) {
			ctx_.is_moving = false;
		}
	}
}

void
TrackerStateMachine::check_geofence () {
	if (!ctx_.gps_fix_obtained) {
		return;
	}

	const auto& data = gps_.get_data ();
	GeoPoint point
		= { (int32_t)(data.latitude * COORD_SCALE), (int32_t)(data.longitude * COORD_SCALE) };

	for (uint8_t i = 0; i < config_.zone_count && i < MAX_GEOFENCE_ZONES; i++) {
		if (!point_in_circle (point, config_.zones[i])) {
			ESP_LOGW (TAG, "Geofence breach: %s", config_.zones[i].name);
			ctx_.is_moving = true;
			geofence_breach_ = true;

			BleAlertData alert = {};
			alert.alert_type = 1;
			alert.zone_index = i;
			alert.latitude = (int32_t)(data.latitude * COORD_SCALE);
			alert.longitude = (int32_t)(data.longitude * COORD_SCALE);
			alert.altitude = (int32_t)(data.altitude * 100);
			alert.timestamp = (uint32_t)(esp_timer_get_time () / 1000000);
			ESP_ERROR_CHECK (ble_.send_alert (alert));
			break;
		}
	}
}

void
TrackerStateMachine::update_activity_time () {
	ctx_.last_activity_time = esp_timer_get_time () / 1000;
}

uint32_t
TrackerStateMachine::get_sleep_duration () const {
	if (ctx_.last_wake == WakeSource::BUTTON) {
		return BUTTON_WAKE_SLEEP_MS;
	}
	return ctx_.is_moving ? config_.sleep_interval_ms : config_.stationary_interval_ms;
}
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

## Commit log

2026-03-21 Initial commit: Pet tracker design and implementation plan
    - AGENTS.md: Development guidelines for the codebase
    - DESIGN.md: Complete pet tracker hardware/software design
    - XIAO ESP32S3 + Wio-SX1262 LoRa + NEO-6M GPS + LIS3DH accelerometer
    - Firmware architecture with state machine
    - LoRa protocol definition
    - Geofencing logic
    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
2026-03-23 Revert "Initialize Rust firmware project with esp-hal"
    This reverts commit 7f6ff42c94768a9d946b61b569af937c6d956786.
    [lib.rs, main.rs]
2026-03-23 Initialize Rust firmware with esp-hal
    - Add Cargo.toml with esp-hal 1.0 (esp32s3), esp-bootloader-esp-idf, critical-section, log
    - Add build.rs with linker configuration
    - Add rust-toolchain.toml specifying esp toolchain
    - Add .cargo/config.toml with ESP32S3 target and build-std configuration
    - Add DEPENDENCIES.md documenting build setup
    - Add src/lib.rs with GPIO and LED driver modules
    - Add src/main.rs: blinks LED on button press
    Build requires esp toolchain from espup. Build in /tmp due to SIGSEGV issues in project directory.
    [lib.rs, main.rs]
2026-03-24 Phase 2: Modular driver structure and devcontainer setup
    - Split monolithic main.cpp into modular driver classes:
    - GpioDriver: base GPIO configuration
    - LedDriver: LED on/off/toggle control
    - ButtonHandler: button debouncing
    - Update CMakeLists.txt to compile all driver sources
    - Add Docker user permission flag (-u) to build.sh
    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
2026-03-24 Phase 3: Testing infrastructure and Docker build fixes
    - Add Unity test component (firmware/components/test/) for driver unit tests
    - Fix Docker build.sh: add -u flag for user permissions, set HOME=/tmp for ccache
    - Add devcontainer/ for VS Code development inside ESP-IDF container
    - Update CI workflow: build tests, run on hardware/QEMU only
    - Tests use ESP-IDF TEST_CASE macro with Unity framework
2026-03-25 Refactors test structure and updates CI configuration
    - Moves driver tests from component-based to dedicated test apps
    - Updates ESP-IDF setup action to v6 for compatibility
    - Adds cache directories to .gitignore for cleaner repository
    - Removes commented-out Rust hooks from pre-commit config
    - Introduces separate test apps for embedded and host testing
2026-03-25 Address PR feedback: add checksum validation, fix timestamp, optimize parse_field
    [gps.cpp]
2026-03-25 Add mock headers for host unit testing with ButtonHandler tests
    - Add mock headers for esp_timer, gpio, esp_err, esp_log
    - Add ButtonHandler tests (4 assertions) - caught and fixed debounce bug
    - Update AGENTS.md with mock testing documentation
    - Testable on Linux without ESP-IDF hardware
    [gpio.h, gpio_mock.cpp, test_button_handler.cpp]
2026-03-25 docs: update documentation to reflect C++ implementation
    - Rewrite DESIGN.md and PLAN.md from Rust to C++ stack
    - Update AGENTS.md with documentation maintenance guidelines
    - Add PLAN.md update instructions after completing features
    - Add DESIGN.md update instructions when architecture changes
    - Update DEPENDENCIES.md for C++/ESP-IDF
    - Update TARGETS.md for ESP32-C6
2026-03-25 Add LED driver unit tests with expanded GPIO mock
    - Add test_led_driver target to CMakeLists.txt
    - Expand gpio.h mock with pullup/pulldown/intr types and proper struct
    - Remove unnecessary timer mock reset from LED test
    - Add test_led_driver to CI workflow
    [gpio.h, test_led_driver.cpp]
2026-03-26 Add multi-board support for ESP32S3 and ESP32C6
    - Create board_config.h with pin definitions for both targets
    - Update build.sh to accept --board esp32s3|esp32c6 flag
    - Change default target to ESP32S3 (primary design target)
    - Update gps.hpp and gps.cpp to use board_config.h pins
    - Update main.cpp to use BOARD_* pin defines
    - Update AGENTS.md with multi-board documentation
2026-03-26 Add LoRa SX1262 driver skeleton (#6)
    * Add LoRa SX1262 driver skeleton
    - Create lora/sx1262.hpp with LoRaDriver class
    - Create lora/sx1262.cpp with basic SPI communication
    - Add init, reset, sleep, standby, set_frequency, set_tx_power
    - Add send and receive functions
    - Add CAD (channel activity detection) support
    - Update CMakeLists.txt to include lora sources
    - Update README ESP-IDF version badge to v6.0
    * Enhance LoRa SX1262 driver with callbacks and improved API
    - Add event callback support for async events (TX_DONE, RX_DONE, etc.)
    - Add send_blocking() with timeout
    - Add set_preamble_length()
    - Add configure_modem() for proper LoRa configuration
    - Add handle_irq() for interrupt proces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
    [board_config.h, main.cpp, sx1262.cpp]
2026-03-26 Add interrupt-driven DIO handling for LoRa driver (#8)
    * Add interrupt-driven DIO handling for LoRa driver
    Replace busy-wait polling with FreeRTOS event group and GPIO ISR.
    Changes:
    - Add FreeRTOS event group (LORA_EVENT_*_BIT) for TX/RX done signaling
    - Add dio1_isr_handler() static ISR that sets event bits and calls callbacks
    - Add gpio_isr_handler_add() and gpio_set_intr_type() to init()
    - Replace send_blocking() busy-wait loop with xEventGroupWaitBits()
    - Replace receive() busy-wait loop with xEventGroupWaitBits()
    - Keep handle_irq() for CAD detection (still uses polling)
    New mock files for host testing:
    - freertos/FreeRTOS.h and event_groups.h mocks
    - driver/gpio_isr.h mock
    - event_g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
    [gpio.h, gpio_mock.cpp, sx1262.cpp]
2026-03-27 Add LIS3DH accelerometer driver for motion detection (#10)
    * Add BLE GATT server skeleton
    - Add ble.hpp with BleServer class and location data structure
    - Add ble.cpp with basic GATT server implementation
    - Uses ESP-IDF Bluedroid stack for BLE communication
    - Service UUID 0x1810 (Location service)
    - Supports device name and location characteristics
    * docs: update PLAN.md to mark BLE GATT server as in progress
    * Address PR review: add mutex, fix memory safety, implement characteristics and advertising
    - Add mutex for thread safety on shared data
    - Use strlcpy for safe string copy
    - Implement add_characteristics() to create location and name chars
    - Add start_advertising() with proper GAP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
    [accelerometer.cpp, board_config.h]
2026-03-27 Add workspace and IDE configuration files
    - Add esp32-tracker.code-workspace for VSCode workspace
    - Add firmware/.vscode/settings.json for firmware-specific settings
    - Update .vscode/settings.json with project settings
    - Update .devcontainer/devcontainer.json
    - Update CMakeLists.txt
2026-03-27 Address PR #13 review comments: fixes for geofence module (#14)
    [BEST PRACTICE] Rename LATLON_MULTIPLIER to COORD_SCALE for clarity
    [SECURITY] Reduce name[32] to name[31] for null terminator safety, add zone_set_name() helper
    [IMPROVEMENT] Fix precision loss: cast to double before division in to_radians()
    [TESTING] Add edge case tests: antimeridian crossing, poles, invalid coords, tiny zones
    [IMPROVEMENT] Add coordinate validation: coordinates_valid() and validation in point_in_circle()
    Note: PR #13 already merged, creating new branch for follow-up fixes
2026-03-27 chore: add VS Code debugging configuration for ESP-IDF
    Added .vscode configuration files (c_cpp_properties.json and launch.json) to enable C/C++ intellisense and debugger attachment for ESP32 development.
2026-03-27 Update PLAN.md: Phase 12 in progress, KiCad project has schematic but no PCB layout yet
2026-03-27 Add programmatic PCB builder and pin mapping docs
    - Add hardware/build_pcb.py: Python script using KiCad pcbnew API
    - Creates 60mm x 40mm board outline
    - Adds mounting holes at corners (M3)
    - Adds silk text labels
    - Add hardware/tracker/PIN_MAPPING.md: Detailed pin mapping docs
    - Update PCB with basic outline and mounting holes
    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
    [tracker.kicad_pcb]
2026-04-05 feat: add state machine for tracker lifecycle management (#15)
    * feat: add state machine for tracker lifecycle management with motion-aware sleep
    * fix: remove duplicate app_main and resolve pin conflicts, add missing driver init calls
    * fix tests: add missing mocks for ISR and event groups, fix geofence test expectations
    * fix tests: add gpio_install_isr_service mock
    * docs: add IDE setup section explaining LSP warnings
    * Adds OpenCode configuration for project permissions
    Configures OpenCode with permission rules for command execution, file access, and watcher exclusions. Sets up instruction sources for AI agents.
    * style: apply GNU-style formatting to firmware with .clang-format co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
    [accelerometer.cpp, board_config.h]
2026-04-05 fix: add missing driver init calls and GPIO wakeup configuration (#16)
    * fix: resolve integration gaps and build errors
    - Add real LoRa TX in state machine with retry logic and BLE fallback
    - Fix ESP-IDF v6.0 API issues (I2C config, GPIO wakeup)
    - Add polygon geofence with ray-casting algorithm
    - Add GPS power control and LoRa sleep/wake management
    - Add interrupt-driven LIS3DH wake for deep sleep
    - Update build.sh for root-owned build directory cleanup
    - Add host ESP-IDF installation guide
    - Add ESP-IDF permissions to opencode.json
    * Adds EIM configuration for ESP32-C3/C6 projects
    Configures ESP-IDF toolchain and environment settings for ESP32-C3 and ESP32-C6 targets.
    Specifies tool vers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
    [accelerometer.cpp, board_config.h, gps.cpp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]
2026-04-05 fix: propagate errors from Config::init/load (#17)
    * fix: propagate errors from Config::init/load and return ESP_ERR_NOT_FOUND when NVS is empty
    Phase 3 error handling:
    - TrackerStateMachine::init() now checks return values from Config::init()
    and Config::load(), transitioning to ERROR state on init failure
    - Config::load() now returns ESP_ERR_NOT_FOUND if no values were read
    from NVS (all defaults were used), ESP_OK otherwise
    * docs: update CHANGELOG and AGENTS.md for Phase 3
    * docs: require CHANGELOG.md update before PR creation
    * Adds GitHub Actions verification to PR review
    Ensures PR agent checks include verification of GitHub Actions status before reviewing code quality and po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
    [state_machine.cpp]
2026-04-13 Configure PR review concurrency and auto-add Opencode agent as reviewer
    Standardizes workflow concurrency group naming for clarity and ensures the Opencode agent (`opencode-agent[bot]`) is automatically added as a reviewer via the GitHub CLI, improving traceability and a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
2026-04-13 feat: add GPS power control and battery driver
    - Add BOARD_GPS_POWER_PIN for MOSFET-controlled GPS power
    - ESP32-S3: GPIO21
    - ESP32-C6: GPIO18
    - Update gps.cpp power_on/power_off to control MOSFET
    - Add battery.hpp with ADC voltage reading and percentage
    - Update DESIGN.md with correct pin mappings for both boards
    - Update PROGRESS.md with completed items
    [battery.hpp, board_config.h, gps.cpp]
2026-04-13 feat(battery): integrate battery reading into state machine transmission
    - Add BatteryDriver to TrackerStateMachine constructor
    - Read battery percentage in try_lora_send() for transmission
    - Initialize battery in main.cpp
2026-04-14 fix(battery): address PR review comments
    - Add initialized_ check in read_voltage_mv() to prevent use of
    uninitialized ADC handle
    - Update voltage calculation comment to clarify ADC_ATTEN_DB_12
    handling (extends range to ~3.1V input)
    - Remove duplicate battery.hpp include from state_machine.cpp
    (already included via state_machine.hpp)
    - Fix constructor initializer order to match member declaration
    order (geofence_breach_ after battery_)
    [battery.hpp, state_machine.cpp]
2026-04-14 docs: update PROGRESS.md - battery reading complete (PR #25)
2026-04-14 Migrate accelerometer to i2c_master driver
2026-04-14 Migrate accelerometer to i2c_master API
2026-04-14 docs: update PROGRESS.md - base station complete
    - Mark Phase 10 (Base station) as done
    - Mark Phase 11 (Flask Web UI) as done
    - Add Base Station section with components and API endpoints
    - Update Overall Health to 8/10
    - Update next steps to focus on PCB design
2026-04-14 fix: UART cleanup, gpio error handling, std::optional battery reads
    - Issue #26: UART cleanup - check return value in Gps destructor
    - Issue #27: GPIO config - graceful error handling instead of ESP_ERROR_CHECK
    - Issue #28: Battery reads - use std::optional instead of sentinel values
    [battery.cpp, battery.hpp, gps.cpp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]
2026-04-18 fix: GPS buffer bounds and LED toggle state (#56)
    * fix(gps): fix buffer bounds and LED toggle state
    - GPS: change < to <= for bounds check to prevent overflow
    - LED: use internal state_ instead of gpio_get_level() for toggle
    * Adds required permissions to GitHub workflows
    Ensures workflows have necessary permissions for ID token, contents, pull requests, and issues to function correctly.
    This addresses potential permission-related failures when the workflows interact with GitHub APIs or resources.
    * Adds timeout and context length configuration
    Sets a 60-minute timeout for the opencode job to prevent hangs
    Increases the context length to 64000 for better model performance
    [gps.cpp]
2026-04-19 fix: replace VLA with std::vector in LoRa receive (#54)
    [sx1262.cpp]
2026-04-19 fix: add static_assert for BLE structs and [[nodiscard]] to methods
    - Add static_assert to verify BLE struct sizes (17 bytes for BleLocationData, 18 for BleAlertData)
    - Add [[nodiscard]] to all esp_err_t returning methods to catch ignored errors at compile time
    - Fix state_machine.cpp to use ESP_ERROR_CHECK on ble_.send_alert() call
    Closes #61, #62
    [state_machine.cpp]
2026-04-19 fix: add error handling to TrackerStateMachine::init()
    - Change init() return type from void to esp_err_t
    - Return error if Config::init() fails
    - Handle error in main.cpp by logging (state machine still continues in degraded mode)
    The state machine holds references to components, so init failures
    don't prevent the machine from running - we log and continue in
    ERROR state if critical (Config) fails.
    Closes #58
    [main.cpp, state_machine.cpp]

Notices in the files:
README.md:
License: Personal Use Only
